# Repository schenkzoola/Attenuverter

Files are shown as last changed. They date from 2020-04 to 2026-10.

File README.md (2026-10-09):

<picture>
  <source media="(prefers-color-scheme: dark)" srcset="docs/images/logo-light.png">
  Schenktronics
</picture>

# Attenuverter

A 6HP Eurorack quad attenuverter from **Schenktronics**. Each of its four channels scales a signal by anywhere from ×1, through zero, to ×−1 (inverted), with a click at zero. Every input is normalled to +5 V, so with nothing plugged in, each channel is a manual offset from −5 V to +5 V.

Attenuverter front panel

## Features

- 6HP Eurorack, 20 mm deep. 16 mA on +12 V and 9 mA on −12 V.
- Four channels, each turning a signal down, off, or upside down
- Knobs with a printed zero mark, straight up at the top of travel
- Inputs normalled to +5 V: four manual offset voltages when nothing's plugged in
- Reverse-power protection on both rails

## Documentation

| Document | For | PDF |
|---|-----|-----|
| [User Manual](docs/manual.md) | Using the module | [PDF](docs/pdf/attenuverter-manual.pdf) |
| [Assembly Guide](docs/assembly-guide.md) | Building the kit | [PDF](docs/pdf/attenuverter-assembly-guide.pdf) |
| [Bill of Materials](docs/BOM.md) ([CSV](docs/BOM.csv)) | Parts and sourcing | |

## Repository layout

```
hardware/
  attenuverter/                Main PCB (KiCad 10)
    Attenuverter.kicad_sch       Schematic
    Attenuverter.kicad_pcb       PCB layout
    Attenuverter.step            3D model
    attenuverter BOM.xlsx        Original BOM spreadsheet
  panel/                       Faceplate (KiCad 10, made as an aluminium PCB)
    AttenuverterFaceplate.kicad_pcb  Faceplate layout
manufacturing/
  attenuverter/                Gerbers, drill and placement files for the main PCB
  panel/                       Gerbers, drill files and the panel drawing (.dxf)
docs/                         Manual, assembly guide, BOM, images
  drawings/                     Scripts that generate the drawings
  pdf/                          PDF versions and their build settings
```

## Fabrication

| Board | Size | Layers | Thickness | Notes |
|---|---|---|---|---|
| Main PCB | 30 × 100 mm | 2 | 1.6 mm | Standard green is fine |
| Faceplate | 30 × 128.5 mm | 1 | 1.6 mm | Aluminium PCB, white solder mask, black silkscreen. Only the front copper layer is used, so FR4 works too. |

Upload the matching `*Gerbers.zip` to any common PCB fab.

## License

This hardware design and its documentation are licensed under [CC BY-NC-SA 4.0](https://creativecommons.org/licenses/by-nc-sa/4.0/). See [LICENSE](LICENSE).

The Schenktronics name and logo are trademarks of Nathan Schenk and are not covered by the CC BY-NC-SA 4.0 license.

## Links

- Tindie: <https://www.tindie.com/products/schenktronics/attenuverter/>
- ModularGrid: <https://modulargrid.net/e/schenktronics-attenuverter>
- Build video: <https://www.youtube.com/watch?v=QJxtZVHBpq0>
- Website: <https://schenktronics.com>

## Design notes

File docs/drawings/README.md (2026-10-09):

# Drawings

The drawings in the docs are generated by three scripts in this repo, plus one that lives elsewhere (see "Outline drawings" below). The three here use only the Python standard library.

| Script | Makes | From |
|---|---|---|
| [`make_panel_svg.py`](make_panel_svg.py) | `panel.svg`, used in the manual, and `panel-plain.svg`, the panel without captions, used on packaging labels | The faceplate KiCad file |
| [`make_assembly_svgs.py`](make_assembly_svgs.py) | `assembly-*.svg`, used in the assembly guide | The main PCB KiCad file |
| [`make_patch_svgs.py`](make_patch_svgs.py) | `patch-*.svg`, the patch examples in the manual | The faceplate KiCad file |

## Panel drawing

The panel drawing in the [user manual](../manual.md) ([`../images/panel.svg`](../images/panel.svg)) is generated from the KiCad faceplate file, [`AttenuverterFaceplate.kicad_pcb`](../../hardware/panel/AttenuverterFaceplate.kicad_pcb).

After changing the faceplate in KiCad, run this from anywhere in the repo:

```sh
python3 docs/drawings/make_panel_svg.py
```

### What it reads

| From the KiCad file | Used for |
|---|---|
| `Edge.Cuts` lines | Panel outline |
| Mounting-hole footprints and their drill sizes | Jacks (Ø6.0), the knobs (Ø7.0) and the rack screw holes |
| `F.SilkS` lines, arcs and text | The channel outlines, the knob scales and the title |
| `F.SilkS` circles | The black rings around the outputs |
| The logo footprint's `F.SilkS` polygons | The Schenktronics logo |

The script tells holes apart by drill size, so if you change a hole size, update `JACK` and `POT` at the top of the script. The knobs are drawn by the script, and the captions ("In 1", "Knob 1" and so on) are added by the script, not read from KiCad.

## Assembly drawings

After changing the main PCB in KiCad, run:

```sh
python3 docs/drawings/make_assembly_svgs.py
```

| Drawing | How it's made |
|---|---|
| `assembly-1-smd.svg` | Back board view, drawn from the pads, back silkscreen and references in the PCB file. U1's pin 1 and the diodes' cathode pads (pad 1) are marked red. |
| `assembly-2-header.svg` | Back board view with J7's outline. The notch position is the gap in the footprint's outline, set in `fig_header()`. |
| `assembly-3-parts.svg` | Front board view, drawn from the board outline, pads and front silkscreen |
| `assembly-4-faceplate.svg` | Side diagram. The part positions along the board come from the PCB file, and the heights are approximate. |
| `assembly-5-solder.svg` | Back board view, with the pot and jack pads to solder |

The side view assumes the faceplate sits 10 mm further up than the PCB, matching the two KiCad files. If you move the parts on either board, update `OFFSET` near the top of the figures section.

## Patch examples

The patch drawings reuse the panel drawing and add module boxes and cables. Each example is a short function in the script, for example:

```python
def invert_envelope(data):
    p = Patch(data)
    p.source("In 1", "Envelope", "out")
    p.dest("Out 1", "Filter", "cutoff CV in")
    p.turn("Knob 1", -110)
    p.note("Knob 1", "Knob 1 left", "upside-down envelope")
    ...
```

Jacks and knobs are named `In 1`–`In 4`, `Out 1`–`Out 4` and `Knob 1`–`Knob 4`, from the top. Sources go on the left, destinations on the right. `turn()` sets a knob's pointer, in degrees from the center click (negative is anticlockwise). `note()` puts a caption to the left of a knob or jack. Pass `color=BLUE` to draw a second signal. To add an example, write a new function, add it to the list in `main()`, and run:

```sh
python3 docs/drawings/make_patch_svgs.py
```

## Outline drawings

`outline-front.svg`, `outline-side.svg`, one `outline-iso-{top,bottom}-{left,right}.svg` per corner, and `outline-bare-parts.svg` (the panel and bare PCB side by side, for the assembly guide's "before you start" shot) are real projections straight from [`ST-03_Attenuverter.step`](../../hardware/ST-03_Attenuverter.step) in `hardware/` — not diagrams. They replace the old product photos in the README, manual and assembly guide. All four isometric corners are generated every run so there's always a fresh set to pick a hero shot from; `outline-iso-top-left.svg` is the one currently used.

**The generator for these doesn't live in this repo.** Unlike the three scripts above, it needs no product-specific logic — point it at any product's STEP files and it works unchanged — so it's kept as one shared tool in the private `schenktronics-business` repo (`claude/skills/schenktronics-product-docs/assets/drawings/make_outline_svg.py`) rather than forked into every product. Regenerate from this repo's root:

```sh
pip install cadquery  # no FreeCAD or other CAD tooling needed
python3 ~/Products/schenktronics-business/claude/skills/schenktronics-product-docs/assets/drawings/make_outline_svg.py \
  --assembly hardware/ST-03_Attenuverter.step \
  --panel hardware/panel/AttenuverterFaceplate.step \
  --board hardware/attenuverter/Attenuverter.step \
  --out docs/images \
  --product "Attenuverter"
```

(or add a view name at the end, e.g. `... outline-front.svg`, to regenerate just that one)

**This is slow, and not predictably so — read the module docstring in that script before touching it.** Short version: a straight-on view down an axis where many cylindrical parts line up end-on (every jack here, viewed from the front — nine of them, more than either the Multiple or Levels) is a degenerate case for exact-BRep HLR. The fix that works for this — a perspective projection with its apex centered on the model, not tilting the orthographic direction — is explained in full in the script itself. That script is the one copy serving every product, so fixes and lessons belong there, not duplicated into each product repo's own docs.

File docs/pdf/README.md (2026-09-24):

# PDFs

Printable versions of the docs:

- [User Manual (PDF)](attenuverter-manual.pdf)
- [Assembly Guide (PDF)](attenuverter-assembly-guide.pdf)

These are built from [`../manual.md`](../manual.md) and [`../assembly-guide.md`](../assembly-guide.md). **Don't edit the PDFs by hand.** Edit the Markdown instead.

The build tool lives in [schenktronics-docs-tools](https://github.com/schenkzoola/schenktronics-docs-tools), so this repo only holds its settings, in [`config.json`](config.json): the product name, PCB version and which documents to build.

## Automatic builds

The [Build PDFs workflow](../../.github/workflows/pdf.yml) rebuilds the PDFs whenever the docs, their images or `config.json` change on `master`, and commits the new PDFs back. After you push a docs change, wait a minute and then `git pull` to get the rebuilt PDFs.

After an update to schenktronics-docs-tools, run the workflow by hand from the repo's **Actions** tab to rebuild with the new version.

## Previewing locally

See [Previewing locally](https://github.com/schenkzoola/schenktronics-docs-tools#previewing-locally) in the tools repo. In short:

```sh
node ~/Products/schenktronics-docs-tools/pdf/build.mjs docs/pdf/config.json
```

Don't commit the PDFs this produces. Let the workflow build the committed copies.

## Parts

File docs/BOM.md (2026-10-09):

# Bill of Materials — Attenuverter v1.0

A machine-readable copy is in [BOM.csv](BOM.csv). The original spreadsheet is [hardware/attenuverter/attenuverter BOM.xlsx](<../hardware/attenuverter/attenuverter BOM.xlsx>).

All the resistors, capacitors, diodes, fuses and chips are surface-mount parts on the back of the board. The resistors and capacitors are 0805 size. Parts marked "or equivalent" can be swapped for any part with the same value, package and pinout.

The **Easy Build Kit** includes a PCB with every surface-mount part below already soldered and tested — you only need to source the through-hole parts.

## Surface-mount parts (back of the board)

| Qty | Reference | Part | Manufacturer / Part No. | Notes |
|----:|---|---|---|---|
| 1 | U1 | Quad JFET op-amp, SOIC-14 | Texas Instruments TL074CDR (TI, Microchip or Analog Devices only) | [Datasheet](https://www.ti.com/lit/ds/symlink/tl074.pdf) |
| 1 | U2 | 5.0 V shunt voltage reference, SOT-23-3 | Texas Instruments LM4040D50IDBZR (TI, Microchip or Analog Devices only) | [Datasheet](https://www.ti.com/lit/ds/symlink/lm4040.pdf). Cathode on pin 1, anode on pin 2. Sets the +5 V that unplugged inputs receive. |
| 16 | R1, R2, R4, R5, R6, R7, R9, R10, R12, R13, R15, R16, R17, R18, R20, R21 | Resistor, 100 kΩ, 1%, 0805 | Yageo RC0805FR-07100KL, or equivalent | |
| 13 | R3, R8, R11, R14, R19, R22–R29 | Resistor, 1 kΩ, 1%, 0805 | Yageo RC0805FR-071KL, or equivalent | R3, R8, R14 and R19 are the output resistors, one per channel. R11 feeds the 5 V reference. R22–R29 are part of the input protection. |
| 4 | C1, C2, C3, C7 | Capacitor, 10 pF, 50 V, C0G/NP0, 0805 | Yageo CC0805JRNPO9BN100, or equivalent | |
| 3 | C4, C6, C9 | Capacitor, 100 nF, 25 V, X7R, 0805 | AVX 08053C104KAT2A, or equivalent | |
| 2 | C5, C8 | Capacitor, 10 µF, 25 V, X5R, 0805 | Taiyo Yuden TMK212BBJ106KG-T, or equivalent | |
| 2 | D1, D2 | Diode, 1 A, 300 V, SMA | ON Semiconductor MRA4003T3G, or equivalent | Reverse-power protection. The cathode (stripe) end matters. |
| 9 | D3–D11 | Diode, 1N4148, SOD-323, 75 V, 150 mA | Diodes Incorporated 1N4148WS-7-F, or equivalent | [Datasheet](https://datasheet.octopart.com/1N4148WS-7-F-Diodes-Inc.-datasheet-7284054.pdf). Input protection. The cathode (stripe) end matters. |
| 2 | F1, F2 | Resettable fuse (PTC), 200 mA hold, 30 V, 1206 | Bel Fuse 0ZCJ0020FF2E, or equivalent | Either way round |

## Through-hole parts

| Qty | Reference | Part | Manufacturer / Part No. | Notes |
|----:|---|---|---|---|
| 1 | J7 | Shrouded pin header, 2 × 5, 2.54 mm, vertical | On Shore Technology 302-S101, or equivalent | Eurorack power connector. Fits on the back. |
| 8 | J1–J6, J8, J9 | 3.5 mm mono switched jack, vertical PCB mount, with nut | QingPu WQP-PJ398SM or WQP518MA, or equivalent. Either one works. CUI MJ-3507 also works, with a ground wire. | [Datasheet / product page](http://www.qingpu-electronics.com/en/products/WQP-PJ398SM-362.html). The inputs use the switched contact for the +5 V normal. The footprint also takes the CUI MJ-3507 ([datasheet](https://www.cuidevices.com/product/resource/mj-3507.pdf)), which is on Mouser: its tip and switch pins go into the board, and its sleeve lug needs a short wire to the jack's square ground pad. |
| 4 | RV1–RV4 | Potentiometer, 100 kΩ linear, 9 mm, vertical PCB mount with board-lock lugs, 6 mm D shaft (20 mm long), bushingless | Bourns PTV09A-4020F-B104, or equivalent | [Datasheet (PTV09 series)](https://www.bourns.com/docs/Product-Datasheets/PTV09.pdf). The panel's printed mark shows zero. No threaded bushing or nut: the pots are held by the PCB's two mounting lugs. An equivalent must fit the 9 mm footprint (3 pins in a row, 2 mounting lugs) and have a 6 mm shaft that fits the knob. |
| 4 | — | Knob, for 6 mm shaft | Davies Molding 1221-J, or equivalent | An equivalent must fit the pot's D shaft. |
| 1 | — | Main PCB, 30 × 100 mm, 2-layer, 1.6 mm FR4 | Schenktronics | Gerbers: [AttenuverterGerbers.zip](../manufacturing/attenuverter/AttenuverterGerbers.zip) |
| 1 | — | Faceplate, 6HP (30 × 128.5 mm), 1.6 mm aluminium PCB | Schenktronics | Gerbers: [AttenuverterFaceplateGerbers.zip](../manufacturing/panel/AttenuverterFaceplateGerbers.zip). Single-sided, so it can also be made in FR4. |
| 1 | — | Eurorack power cable, 10-pin to 16-pin | | Red stripe marks −12 V. |

## Not included

| Qty | Part | Notes |
|----:|---|---|
| 4 | M3 rack screws | Supplied with most Eurorack cases. Two, in diagonally opposite corners, will hold the module. |

## Ordering the parts

There's a [Mouser project](https://www.mouser.com/ProjectManager/ProjectDetail.aspx?AccessID=490ed0ce39) with the parts for building from bare PCBs. Mouser doesn't stock QingPu jacks, so the project uses CUI MJ-3507 jacks instead. They fit the board, but each one needs a ground wire: see the note in Step 6 of the [assembly guide](assembly-guide.md#step-6--solder-the-pots-and-jacks).

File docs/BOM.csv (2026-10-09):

Qty | Reference | Description | Manufacturer | Part Number | Link
1 | U1 | Quad JFET op-amp, SOIC-14. Use TI, Microchip or Analog Devices only | Texas Instruments | TL074CDR | https://www.ti.com/lit/ds/symlink/tl074.pdf
1 | U2 | 5.0V shunt voltage reference, SOT-23-3, cathode pin 1, anode pin 2. Use TI, Microchip or Analog Devices only | Texas Instruments | LM4040D50IDBZR | https://www.ti.com/lit/ds/symlink/lm4040.pdf
16 | R1, R2, R4, R5, R6, R7, R9, R10, R12, R13, R15, R16, R17, R18, R20, R21 | Resistor, 100k, 1%, 0805 | Yageo | RC0805FR-07100KL
13 | R3, R8, R11, R14, R19, R22, R23, R24, R25, R26, R27, R28, R29 | Resistor, 1k, 1%, 0805 | Yageo | RC0805FR-071KL
4 | C1, C2, C3, C7 | Capacitor, 10pF, 50V, C0G/NP0, 0805 | Yageo | CC0805JRNPO9BN100
3 | C4, C6, C9 | Capacitor, 100nF, 25V, X7R, 0805 | AVX | 08053C104KAT2A
2 | C5, C8 | Capacitor, 10uF, 25V, X5R, 0805 | Taiyo Yuden | TMK212BBJ106KG-T
2 | D1, D2 | Diode, 1A, 300V, SMA | ON Semiconductor | MRA4003T3G
9 | D3, D4, D5, D6, D7, D8, D9, D10, D11 | Diode, 1N4148, SOD-323, 75 V, 150 mA | Diodes Incorporated, or equivalent | 1N4148WS-7-F | https://datasheet.octopart.com/1N4148WS-7-F-Diodes-Inc.-datasheet-7284054.pdf
2 | F1, F2 | Resettable fuse (PTC), 200mA hold, 30V, 1206 | Bel Fuse | 0ZCJ0020FF2E
1 | J7 | Shrouded pin header, 2x5, 2.54mm, vertical | On Shore Technology | 302-S101
8 | J1-J6, J8, J9 | 3.5mm mono switched jack, vertical, with nut (CUI MJ-3507 also works, with a ground wire from its sleeve lug to the square pad) | QingPu | WQP-PJ398SM or WQP518MA | http://www.qingpu-electronics.com/en/products/WQP-PJ398SM-362.html
4 | RV1-RV4 | Potentiometer, 100k linear, 9mm, bushingless, 6mm D shaft (20mm long) (or equivalent) | Bourns | PTV09A-4020F-B104 | https://www.bourns.com/docs/Product-Datasheets/PTV09.pdf
4 |  | Knob, fits 6mm D shaft (or equivalent) | Davies Molding | 1221-J
1 |  | Main PCB, 30x100mm, 2-layer, 1.6mm | Schenktronics | Attenuverter v1.0
1 |  | Faceplate, 6HP, 1.6mm aluminium PCB | Schenktronics | Attenuverter Faceplate
1 |  | Eurorack power cable, 10-pin to 16-pin

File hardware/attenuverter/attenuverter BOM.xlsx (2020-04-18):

Manufacturer Part Number | Manufacturer | Customer Reference | Reference Designator | Quantity | Description
CC0805JRNPO9BN100 | Yageo |  | C1, C2, C3, C7 | 4 | CAP CER 10PF 50V C0G/NPO 0805
08053C104KAT2A | AVX Corporation |  | C4, C6, C9 | 3 | CAP CER 0.1UF 25V X7R 0805
TMK212BBJ106KG-T | Taiyo Yuden |  | C5, C8 | 2 | CAP CER 10UF 25V X5R 0805
MRA4003T3G | ON Semiconductor |  | D1, D2 | 2 | DIODE GEN PURP 300V 1A SMA
0ZCJ0020FF2E | Bel Fuse Inc. |  | F1, F2 | 2 | PTC RESET FUSE 30V 200MA 1206
MJ-3507 | CUI Devices |  | J1, J2, J3, J4, J5, J6, J8, J9 | 8 | CONN AUDIO JACK 3.5MM MONO
302-S101 | On Shore Technology Inc. |  | J7 | 1 | CONN HEADER VERT 10POS 2.54MM
LM4040DYM3-5.0-TR | Microchip Technology |  | U2 | 1 | IC VREF SHUNT 1% SOT23-3
RC0805FR-07100KL | Yageo |  | R1, R2, R4, R5, R6, R7, R9, R10, R12, R13, R15, R16, R17, R18, R20, R21 | 16 | RES SMD 100K OHM 1% 1/8W 0805
RC0805FR-07100RL | Yageo |  | R3, R8, R14, R19 | 4 | RES SMD 100 OHM 1% 1/8W 0805
RC0805FR-071KL | Yageo |  | R11 | 1 | RES SMD 1K OHM 1% 1/8W 0805
TL074CDR | Texas Instruments |  | U1 | 1 | IC OPAMP JFET 4 CIRCUIT 14SOIC
PTV09A-4225F-B104 | Bourns Inc. |  | RV1, RV2, RV3, RV4 | 4 | POT 100K OHM 1/20W CARBON LINEAR
1221-J | Davies Molding, LLC | Knobs |  | 4 | KNOB SERRATED 0.236" PLASTIC

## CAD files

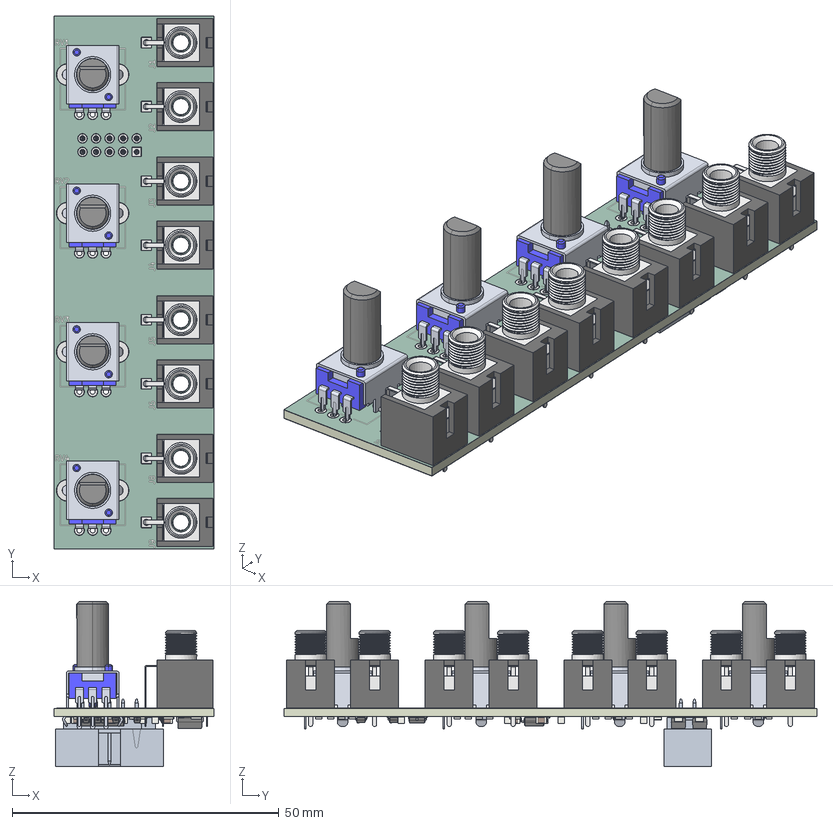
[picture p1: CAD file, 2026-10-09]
hardware/attenuverter/Attenuverter.step
30.0 x 100.0 x 31.0 mm
Thonkiconn - PJ398SM v10 x 8
PTV09A-4X20F-XXXCX_2 x 4
PTV09A-4X20F-XXXCX x 4
C_0805_2012Metric x 9
D_SMA x 2
SOT-23
R_0805_2012Metric x 29
Fuse_1206_3216Metric x 2
SOIC-14_3.9x8.7mm_P1.27mm
D_SOD-323 x 9
Attenuverter-unsaved-export-JzEjut_copper
Attenuverter-unsaved-export-JzEjut_pad
Attenuverter-unsaved-export-JzEjut_via
Attenuverter-unsaved-export-JzEjut_silkscreen x 2
Attenuverter-unsaved-export-JzEjut_soldermask x 2
Attenuverter-unsaved-export-JzEjut_PCB

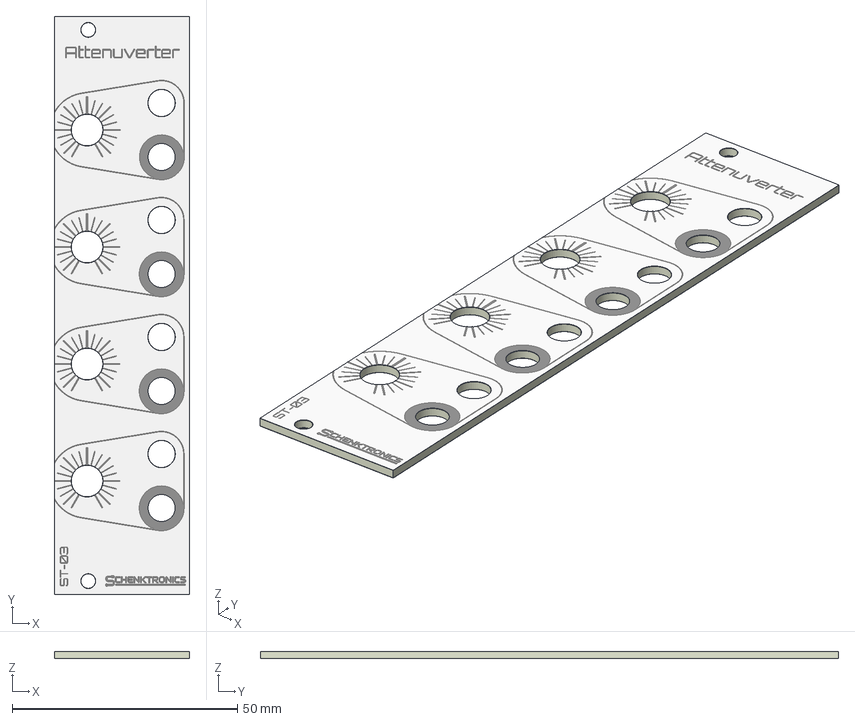
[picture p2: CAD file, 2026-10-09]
hardware/panel/AttenuverterFaceplate.step
30.0 x 128.5 x 1.64 mm
AttenuverterFaceplate-unsaved-export-2P21R3_copper
AttenuverterFaceplate-unsaved-export-2P21R3_silkscreen
AttenuverterFaceplate-unsaved-export-2P21R3_soldermask x 2
AttenuverterFaceplate-unsaved-export-2P21R3_PCB

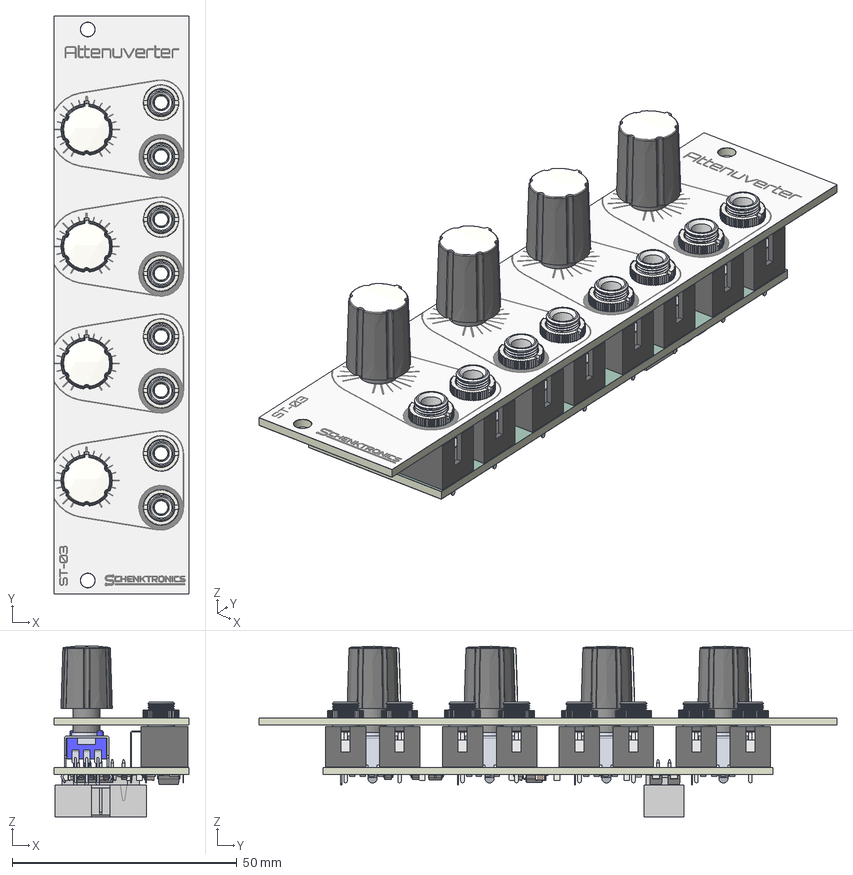
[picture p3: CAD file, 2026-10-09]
hardware/ST-03_Attenuverter.step
30.0 x 128.5 x 37.9 mm
Thonkiconn - PJ398SM v10 x 8
PTV09A-4X20F-XXXCX_2 x 4
PTV09A-4X20F-XXXCX x 4
C_0805_2012Metric_1 x 9
D_SMA_1 x 2
SOT-23_1
R_0805_2012Metric_1 x 29
Fuse_1206_3216Metric_1 x 2
SOIC-14_3.9x8.7mm_P1.27mm_1
D_SOD-323_1 x 9
Attenuverter-unsaved-export-JzEjut_copper
Attenuverter-unsaved-export-JzEjut_pad
Attenuverter-unsaved-export-JzEjut_via
Attenuverter-unsaved-export-JzEjut_silkscreen
Attenuverter-unsaved-export-JzEjut_silkscreen_1
Attenuverter-unsaved-export-JzEjut_soldermask
Attenuverter-unsaved-export-JzEjut_soldermask_1
Attenuverter-unsaved-export-JzEjut_PCB
AttenuverterFaceplate-unsaved-export-2P21R3_copper
AttenuverterFaceplate-unsaved-export-2P21R3_silkscreen
AttenuverterFaceplate-unsaved-export-2P21R3_soldermask
AttenuverterFaceplate-unsaved-export-2P21R3_soldermask_1
AttenuverterFaceplate-unsaved-export-2P21R3_PCB
Davies 1221-J x 4

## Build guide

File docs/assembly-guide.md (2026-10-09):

# Attenuverter — Assembly Guide

This kit has 139 solder joints, 85 of them on surface-mount parts: 0805 resistors and capacitors, and a SOIC-14 chip. It takes about 1½–2 hours if you're experienced with surface-mount soldering, and longer if you're not. If you haven't soldered surface-mount parts before, practice on a scrap board first, or start with a through-hole kit such as the [Passive Attenuator](https://github.com/schenkzoola/ST02-attenuator).

**Building the Easy Build Kit?** Its board arrives with every surface-mount part already soldered and tested, so skip [Step 1](#step-1--solder-the-surface-mount-parts) and start at [Step 2](#step-2--fit-the-power-header). That leaves 54 through-hole joints, about 45–60 minutes, and no surface-mount soldering at all.

**Prefer to watch?** There's a video of the whole build: [Watch me build a surface mount attenuverter!](https://www.youtube.com/watch?v=QJxtZVHBpq0)

The faceplate and the bare PCB, before assembly

## What you need

### Kit contents

Check your kit against this list before you start (full details in the [BOM](BOM.md)).

**Easy Build Kit:** your board already has these soldered on — check they're present and well soldered, don't source loose parts for them:

- [ ] 1 × TL074 quad op-amp (U1, 14 pins)
- [ ] 1 × LM4040 5 V reference (U2, 3 pins)
- [ ] 16 × 100 kΩ resistors
- [ ] 13 × 1 kΩ resistors
- [ ] 4 × 10 pF capacitors
- [ ] 3 × 100 nF capacitors
- [ ] 2 × 10 µF capacitors
- [ ] 2 × diodes (D1, D2)
- [ ] 9 × 1N4148 diodes (D3–D11)
- [ ] 2 × resettable fuses (F1, F2)

**Every kit**, loose:

- [ ] 1 × main PCB (Easy Build Kit: surface-mount parts above already soldered on)
- [ ] 1 × faceplate
- [ ] 1 × 10-pin shrouded power header
- [ ] 8 × 3.5 mm jacks with nuts
- [ ] 4 × potentiometers
- [ ] 4 × knobs
- [ ] 1 × power cable, 10-pin to 16-pin

If you're soldering the surface-mount parts yourself, the capacitors have no markings, so the three values look alike, and resistor markings vary between makers. Keep each value in its labelled strip or bag until you place it.

### Tools

- Soldering iron with a fine tip (about 330–360 °C for leaded solder)
- Thin solder, 0.5 mm or less
- Fine tweezers (Step 1 only — skip if you have the Easy Build Kit)
- Flux (a pen or syringe) and solder wick, for fixing bridges (Step 1 only — skip if you have the Easy Build Kit)
- A magnifier or loupe, to inspect the surface-mount joints
- Flush cutters
- Multimeter with continuity (beep), diode test and DC voltage modes
- Nut driver or wrench for the jack nuts (optional, but it avoids scratching the panel)

## Before you start

- The board has two sides. The **back** has the small rectangular pads for the surface-mount parts, and is printed "Attenuverter v1.0 / schenktronics.com" and "Red Stripe". The **front** has the outlines for the pots and jacks (RV1–RV4, J1–J9).
- Build in this order: surface-mount parts, then the power header, then the pots and jacks. Each stage is easier while the next one isn't in the way. (Easy Build Kit: the surface-mount stage is already done — start at the power header.)
- **Don't solder the pots or jacks until the faceplate is fitted.** The faceplate holds them in line while you solder.

## Step 1 — Solder the surface-mount parts

**Easy Build Kit: skip this step.** Your board already has these parts soldered and tested at the factory. Go to [Step 2](#step-2--fit-the-power-header).

All of these go on the back of the board. For every two-pad part, use the same method:

1. Put a little solder on one pad.
2. Hold the part with tweezers, slide it onto the pads, and reheat the tinned pad so the part settles flat.
3. Solder the other pad, then go back and touch up the first one.

Work in this order, from the most difficult part to the easiest:

1. **U1 (TL074).** Line up the dot or notch on the chip with the pin 1 pad, marked red in the drawing. Tack one corner pin, check that all 14 pins sit on their pads, then tack the opposite corner. Solder the rest. If two pins bridge, add flux and clean the bridge with wick.
2. **U2 (LM4040).** It only fits one way round: two pins on one side, one on the other.
3. **Resistors**, one value at a time:

   | Value | Where |
   |-------|-------|
   | 100 kΩ (16) | R1, R2, R4, R5, R6, R7, R9, R10, R12, R13, R15, R16, R17, R18, R20, R21 |
   | 1 kΩ (13) | R3, R8, R11, R14, R19, R22, R23, R24, R25, R26, R27, R28, R29 |

4. **Capacitors**, one value at a time. Open one strip at a time so you don't mix them up.

   | Value | Where |
   |-------|-------|
   | 10 pF (4) | C1, C2, C3, C7 |
   | 100 nF (3) | C4, C6, C9 |
   | 10 µF (2) | C5, C8 |

5. **D1 and D2.** The stripe (cathode) end goes on the red pad in the drawing: the end of the outline with the line across it. These diodes protect the module if the power cable goes in backwards, so a reversed diode shorts the power rail.
6. **D3–D11**, the nine 1N4148 input clamp diodes. The stripe end goes on the red pad, as for D1 and D2. The stripe goes on the +12 V pad for D5, D6, D8 and D10, and on the input-side pad for D4, D7, D9 and D11. A reversed clamp lets its input drift to about +11 V or −11 V, so check each one against the drawing before you solder it.
7. **F1 and F2**, the resettable fuses. They work either way round.

Back of the PCB with every surface-mount part labelled. U1's pin 1 pad and the cathode pads of D1 to D11 are red.

Check every joint with a magnifier. Each one should be a smooth fillet from the pad up the end of the part, with no bridges between U1's pins.

## Step 2 — Fit the power header

1. Push J7 into its holes from the **back**. Turn it so the notch in the shroud lines up with the gap in the printed outline. Pin 1 (the square pad) is −12 V, next to the "Red Stripe" marking.
2. Turn the board over and solder one pin on the front. Check that the header sits flat against the board; if not, reheat the pin and press it down.
3. Solder the other nine pins.

Back of the PCB with J7 outlined in red. Pin 1, the square pad, is next to the Red Stripe marking, and the shroud's notch goes at the gap in the outline.

## Step 3 — Check for shorts

Before adding the rest, check the power rails with a multimeter in diode test mode (the diode symbol). No power is needed. Probe the header pins from the front of the board. Worth doing on the Easy Build Kit too: the factory tested the surface-mount side, but you've just soldered the header yourself.

Use diode test mode, not resistance mode. Most meters test resistance at too low a voltage to turn a diode on, so a diode fitted backwards reads as an open circuit in resistance mode and looks fine. Diode test mode uses a higher voltage and shows a diode's forward voltage instead.

| Test | Expected result |
|---|---|
| Red probe on pin 9 (+12 V), black on pin 3 (ground) | OL, or a high reading. It may count up for a moment while the capacitors charge. |
| Red probe on pin 3 (ground), black on pin 1 (−12 V) | OL, or a high reading. It may count up for a moment. |
| Red probe on pin 3 (ground), black on pin 9 (+12 V) | About 0.5–0.7 V: D1 conducting. |
| Red probe on pin 1 (−12 V), black on pin 3 (ground) | About 0.5–0.7 V: D2 conducting. |
| Red probe on pin 9 (+12 V), black on pin 1 (−12 V) | OL. A reading of about 1–1.5 V means two clamp diodes on one channel are both reversed and shorting the rails. |

What a wrong reading means:

- **Near 0 V** (many meters also beep) in any test: a short. Look for a solder bridge on U1 or on the power header.
- **About 0.5–0.7 V in the first or second test:** D1 (first test) or D2 (second test) is fitted backwards. Fitted like that, it would short the rail as soon as you power on.
- **OL in the third or fourth test:** D1 or D2 is missing, fitted backwards, or not soldered.
- **About 1–1.5 V in the fifth test:** both clamp diodes of one channel are fitted backwards. That shorts the power rails through them. Check the pair in the next table.

The input clamp diodes (D3–D11) are on the back of the board, so you can test each one on its own two pads, before the pots and jacks go in. Use the same method: red probe on the plain end, black on the stripe end.

| Diode | Red probe on | Black probe on | Expected |
|---|---|---|---|
| D3 | GND pad | +5 V pad | About 0.5–0.7 V |
| D4 | −12 V pad | input-side pad | About 0.5–0.7 V |
| D5 | input-side pad | +12 V pad | About 0.5–0.7 V |
| D6 | input-side pad | +12 V pad | About 0.5–0.7 V |
| D7 | −12 V pad | input-side pad | About 0.5–0.7 V |
| D8 | input-side pad | +12 V pad | About 0.5–0.7 V |
| D9 | −12 V pad | input-side pad | About 0.5–0.7 V |
| D10 | input-side pad | +12 V pad | About 0.5–0.7 V |
| D11 | −12 V pad | input-side pad | About 0.5–0.7 V |

If a diode in this table reads OL, it's fitted backwards, missing, or not soldered.

## Step 4 — Fit the pots and jacks

1. Push the four pots into RV1–RV4 from the **front** of the PCB. Each pot fits only one way round: the three pins go in the row of three small holes and the two mounting lugs go in the large holes. The lugs clip into the board and hold the pot in place.
2. Insert the eight jacks into J1–J6, J8 and J9 from the front. Make sure each jack sits flat, with all three legs through their pads.
3. Don't solder anything yet.

Front of the PCB with the positions of RV1 to RV4 and the eight jacks highlighted

## Step 5 — Fit the faceplate

1. Remove the nuts from the jacks. The pots have no nuts.
2. Lower the faceplate over the parts. The "Attenuverter" label goes at the top, over J1 and RV1. The pot shafts go through the four larger holes.
3. Put the jack nuts back on and tighten them **finger-tight** for now.
4. Check that each pot shaft is centered in its hole, and that the PCB is parallel to the faceplate. The shafts are thinner than their holes, and nothing but the solder will hold them, so centering them now stops the knobs rubbing later. The legs have a little play in their holes, which gives you room to adjust.
5. Tighten the jack nuts snugly. Do not overtighten them, because that can crack the jack threads or mark the panel.

Exploded side view: pots and jacks on the PCB, the faceplate above them, and the jack nuts on top

## Step 6 — Solder the pots and jacks

Turn the assembly over and solder from the back of the PCB, between the surface-mount parts.

1. Tack one leg of each part: the square pad of each jack and the middle pin of each pot. Then check again that the pot shafts are still centered. If one isn't, reheat that joint and adjust.
2. Solder the remaining pins and pads.
3. Solder the eight large mounting-lug pads of the pots. They connect to ground, so they take a little longer to heat. Hold the iron on until the solder flows into the hole.
4. Trim any long leads with flush cutters.

> **Building with CUI MJ-3507 jacks** (the ones in the Mouser parts list)? Their tip and switch pins go into the board, but the sleeve is a solder lug on the jack, not a pin. Tack the tip pin instead of the square pad, then solder a short wire from each jack's sleeve lug to its square pad. Without the wire, the jack has no ground.

Back of the PCB: one pad per pot and jack to tack first is filled red, and the other pads, including the pot lugs, are outlined in red

## Step 7 — Fit the knobs

Push each knob onto its pot shaft. The flat on the shaft sets the knob's position. Turn each knob so the pointer points straight up, at the long mark on the panel. Check that each knob turns without rubbing on the panel.

## Step 8 — Test

### Without power

Repeat the Step 3 short test on the header pins. Then plug a patch cable into each jack in turn and check its sleeve against a ground pin (pins 3–8) on the header: every jack should beep.

### With power

Connect the module to your case (see [Install](#step-9--install)), with the red stripe on −12 V at both ends, and power on. If anything gets hot or smells, power off at once and check the diodes and U1.

With nothing plugged into the inputs, measure each output with the multimeter on DC volts. Plug a patch cable into the output and probe its tip and sleeve.

| Knob | Expected output |
|---|---|
| Fully clockwise | About +5 V |
| Pointer centered, at the long mark | About 0 V |
| Fully anticlockwise | About −5 V |

Then patch an LFO or other moving signal into each input in turn, and listen or watch as you turn the knob from one end to the other: the signal should shrink to nothing at the center and grow again, inverted, on the other side.

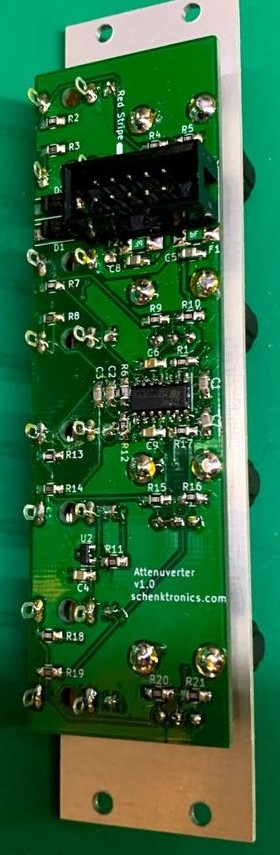
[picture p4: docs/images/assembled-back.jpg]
Back of a finished module, for comparing solder joints


## Step 9 — Install

Install the module in your case with the included power cable and four M3 rack screws (two will do). The details, and how to use the module, are in the [User Manual](manual.md#installation).

Assembled module, isometric view

## Troubleshooting

| Symptom | Likely cause |
|---|---|
| Nothing works, and the power supply struggles, a fuse trips or U1 gets hot | A short on a power rail: a solder bridge on U1, U1 fitted the wrong way round (check its pin 1), a diode fitted backwards (D1–D11), or the power cable plugged in backwards. A rail test of about 1–1.5 V points to a reversed clamp pair. |
| An unplugged input reads about +11 V, or about −11 V, instead of +5 V | One clamp diode on that input is fitted backwards. For channel 1 (RV1, jack J1) the +12 V diode is D5 and the −12 V diode is D4. For channel 2 (RV2, J3): D6 and D7. Channel 3 (RV3, J5): D8 and D9. Channel 4 (RV4, J8): D10 and D11. About +11 V means the +12 V diode is reversed, and about −11 V means the −12 V diode is. |
| No channel works, but nothing gets hot | The power header isn't soldered well. |
| Empty inputs give 0 V at every knob position | U2 or R11 isn't soldered well, or U2 is missing: the +5 V normal isn't there. |
| One channel is dead | A bad joint on that channel's jacks, pot, or its resistors and capacitor. Check the pins of U1 for that channel too. |
| An output is stuck near +10 V or −10 V | A missing or badly soldered resistor on that channel, so the op-amp has no feedback. Check the 100 kΩ resistors near it. |
| An empty input works, but a plugged-in signal doesn't come through | A bad joint on that input jack's tip leg. |
| A knob works backwards (clockwise inverts) | The pot is a different type from the one in the BOM. |
| The output isn't quite 0 V with the pointer centered | A small offset is normal. A large one means a resistor of the wrong value next to that pot: check the two 100 kΩ resistors beside it. |
| A knob rubs on the panel | The shaft isn't centered in its hole, or the knob is pushed on too far. |

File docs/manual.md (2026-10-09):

# Attenuverter — User Manual

Attenuverter front panel

## Overview

The Attenuverter is a 6HP Eurorack utility module with four identical channels. Each channel scales the signal at its input by an amount set by its knob, anywhere from full level, through zero, to full level upside down (inverted).

Each input is normalled to +5 V. With nothing plugged into an input, its output is a steady voltage from −5 V to +5 V, set by the knob. So each channel is also a manual offset or CV source.

The module is active: it needs ±12 V from your case's power supply.

## Specifications

| | |
|---|---|
| Format | Eurorack, 6HP |
| Panel | 30 × 128.5 mm |
| Depth | 20 mm |
| Power | 16 mA on +12 V, 9 mA on −12 V, no +5 V. 10-pin header. |
| Protection | Reverse-power diodes and resettable fuses on both rails, and clamp diodes on each input |
| Jacks | 8 × 3.5 mm mono (TS): 4 inputs, 4 outputs |
| Controls | 4 × knobs with a printed zero mark (100 kΩ linear potentiometers) |
| Range | ×−1 (fully anticlockwise) to 0 (center) to ×+1 (fully clockwise) |
| Unplugged inputs | +5 V, so the output is −5 V to +5 V |
| Input impedance | About 33–52 kΩ, depending on the knob (calculated) |
| Output impedance | 1 kΩ |
| Signals | Audio, CV, gates and bipolar signals. DC-coupled. |
| Output swing | About ±10 V, limited by the op-amp running on ±12 V |

Side view of the assembled module, showing the panel, PCB, jacks and pots

## Panel layout

Panel layout: four channels, each with a knob on the left, an input jack at the top right and an output jack with a black ring below it

The panel has four identical channels, numbered 1 to 4 from the top. Each channel is outlined, with its knob on the left and two jacks on the right. The top jack is the input. The jack with the **black ring** is the output.

## Using the module

### Knobs

Each knob sets how much of the input reaches the output, and which way up:

| Knob position | Output |
|---|---|
| Fully clockwise | The input, unchanged (×1) |
| Halfway between the center and fully clockwise | About a third of the input (×0.36) |
| Center | Nothing (×0) |
| Halfway between the center and fully anticlockwise | About a third of the input, inverted (×−0.36) |
| Fully anticlockwise | The input, inverted (×−1) |

"Inverted" means turned upside down: a rising envelope falls instead, and a +3 V CV becomes −3 V.

The panel prints a long mark at the top of each knob's travel, where the output is zero. Line the knob's pointer up with it to return a channel to "off".

The knobs are center-weighted. Halfway to either end gives about a third of the signal rather than half, so more of the knob's travel is spent on small amounts. That's where fine control usually matters, for example for a gentle vibrato or a small filter wobble.

### Normalled inputs: offset voltages

Each input is normalled to +5 V. When nothing is plugged into an input, the channel gets +5 V instead. The output is then a steady voltage:

- **Fully clockwise:** +5 V
- **Center:** 0 V
- **Fully anticlockwise:** −5 V

Use this as a manual CV knob for a module that has no knob of its own, to transpose a sequence, or to shift an LFO up or down through a DC mixer. Plugging a cable into the input breaks the normal.

### Using it on audio

On audio, a channel is a volume control that can also flip the phase. Mixing a signal with an inverted copy of itself cancels it out.

## Patch examples

Each drawing shows the module that sends the signal on the left and the modules that receive it on the right.

### Invert an envelope

An envelope patched into In 1, with Out 1 going to a filter's cutoff CV input and Knob 1 turned to the left

Turn Knob 1 left of center and the envelope comes out upside down: instead of opening the filter, each note closes it. Raise the filter's cutoff knob so there's somewhere for the envelope to sweep down from.

### Set the depth of an LFO

An LFO patched into In 2, with Out 2 going to a VCO's pulse width CV input and Knob 2 turned a little to the right

Many CV inputs have no level control, so a full-size LFO sweeps them from end to end. Patch the LFO through a channel and use its knob to set the depth. Just right of center gives a subtle movement; turn left of center to reverse the LFO's direction.

### Offset an LFO

An LFO through channel 3 into a DC mixer's first input, and Out 4 into the mixer's second input with In 4 empty

Channel 3 sets the LFO's depth. In 4 is empty, so Knob 4 gives a steady voltage between −5 V and +5 V. Add the two in a DC-coupled mixer and the LFO moves around a center point you choose with Knob 4.

## Good practice

- **Don't patch outputs together.** Joining an Out jack to another module's output makes the two outputs fight each other, and the result is unpredictable. The 1 kΩ output resistors help protect this module, but the other module may not be protected. Use a mixer to combine signals.
- **An empty input isn't silent.** An unplugged input carries +5 V, so its output isn't 0 V unless the knob is at the center. If a patch has an unexpected offset, check for a channel with an empty input.
- **The zero mark is close to zero, not exact.** Pots vary, so there may be a very small signal left even with the pointer lined up. If you need true silence, unplug the output.
- **Pitch CV (V/oct):** scaling a pitch CV changes the intervals, so the oscillator won't play in tune. Fully clockwise is close to ×1 but isn't calibrated for 1 V/oct. That can be a creative effect, but it's not a way to transpose. To transpose, use an empty input as an offset and add it to the pitch CV in a DC mixer.
- **Signals above about ±10 V clip.** The op-amp can't swing further than that on ±12 V. Standard Eurorack signals fit.

## Installation

1. Power off your case.
2. Connect a 10-pin to 16-pin Eurorack power cable to the header on the back of the module. The red stripe goes to **−12 V**, marked "Red Stripe" and "−12v" on the board. At the bus board end, the red stripe also goes to −12 V, usually marked on the bus.
3. Place the module in any 6HP space.
4. Secure it with four M3 rack screws, one in each corner hole. Two screws, in diagonally opposite corners, will hold it if your case is short of screws, but four look neater. Do not overtighten them.
5. Power on and check that turning a knob with an empty input moves its output between −5 V and +5 V.

The module is protected against a cable plugged in backwards, but don't rely on it. Always check the red stripe before powering on.

## Circuit

Each channel is one section of a TL074 quad op-amp (U1), wired as a differential amplifier. Each input jack goes through a 1 kΩ resistor to a node. Two clamp diodes hold that node between +12 V and −12 V, so a signal beyond about ±12 V can't reach the op-amp. From the node, the signal goes to both ends of the circuit: through a 100 kΩ resistor to the op-amp's inverting input, and to one end of the knob's potentiometer, whose other end is grounded. The pot's wiper drives the op-amp's non-inverting input. With equal 100 kΩ resistors, the output is 2 × (wiper) − (input), so it runs from −1× the input with the wiper at ground to +1× with the wiper at the input, and is zero at the center. Two 100 kΩ resistors across the two halves of each pot give the center-weighted response. A 10 pF capacitor in the feedback loop keeps the op-amp stable, and a 1 kΩ resistor protects each output.

The inputs are switched jacks. Their normalling contacts connect to a 5.0 V reference (U2, an LM4040, fed from +12 V through a 1 kΩ resistor), so each unplugged input sees +5 V.

The power input has a resettable fuse and a reverse-biased diode on each rail. If the power cable is plugged in backwards, the diodes conduct and the fuses trip, protecting the circuit. The schematic is in [hardware/attenuverter/Attenuverter.kicad_sch](../hardware/attenuverter/Attenuverter.kicad_sch).

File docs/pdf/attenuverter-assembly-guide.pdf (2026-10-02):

This kit has 139 solder joints, 85 of them on surface-mount parts: 0805 resistors and capacitors, and a SOIC-14 chip. It takes about 1½–2 hours if you're experienced with surface-mount soldering, and longer if you're not. If you haven't soldered surface-mount parts before, practice on a scrap board first, or start with a
through-hole kit such as the Passive Attenuator (https://github.com/schenkzoola/Attenuator).

Building the Easy Build Kit? Its board arrives with every surface-mount part already soldered and tested, so skip Step 1 and start at Step 2. That leaves 54 through-hole joints, about 45–60 minutes, and no surface-mount soldering at all.

Prefer to watch? There's a video of the whole build: Watch me build a surface mount attenuverter! (https://www.y

outube.com/watch?v=QJxtZVHBpq0) (https://www.youtube.com/watch?v=QJxtZVHBpq0)

## What you need

Kit contents
Check your kit against this list before you start (full details in the BOM
(https://github.com/schenkzoola/Attenuverter/blob/master/docs/BOM.md)).

Easy Build Kit: your board already has these soldered on — check they're present and well soldered, don't source loose parts for them:

1 × TL074 quad op-amp (U1, 14 pins)
1 × LM4040 5 V reference (U2, 3 pins)
16 × 100 kΩ resistors
4 × 100 Ω resistors
1 × 1 kΩ resistor
4 × 10 pF capacitors
3 × 100 nF capacitors
2 × 10 µF capacitors
2 × diodes (D1, D2)
2 × resettable fuses (F1, F2)

Every kit, loose:

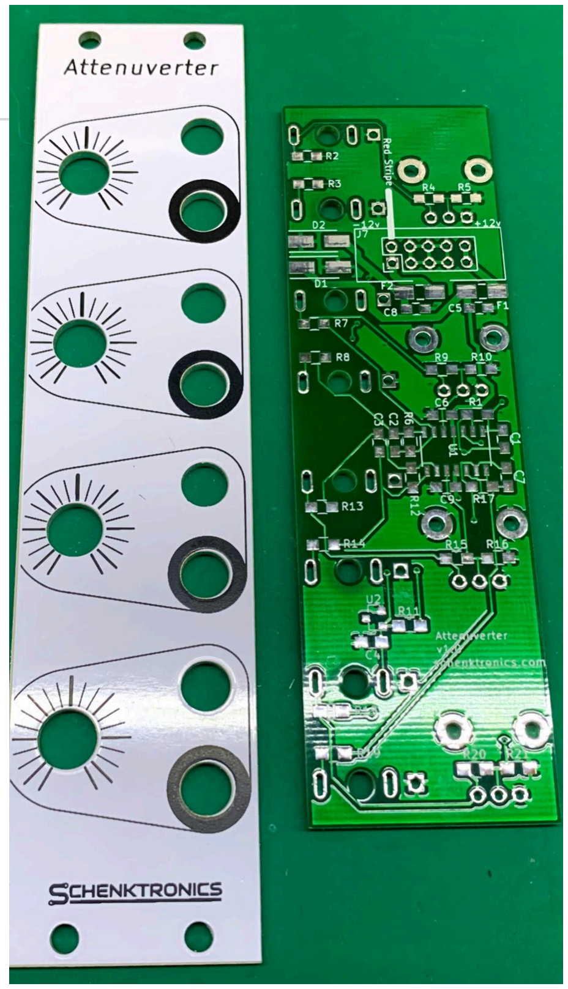
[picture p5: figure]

1 × main PCB (Easy Build Kit: surface-mount parts above already soldered on) 1 × faceplate
1 × 10-pin shrouded power header

# Attenuverter

## Assembly Guide

For PCB v1.0 · Updated 2026-10-02
Official version: github.com/schenkzoola/Attenuverter
Attenuverter · Assembly Guide · PCB v1.0 | schenktronics.com · CC BY-NC-SA 4.0 | Page 1 of 8

8 × 3.5 mm jacks with nuts
4 × potentiometers
4 × knobs
1 × power cable, 10-pin to 16-pin

If you're soldering the surface-mount parts yourself, the capacitors have no markings, so the three values look alike, and resistor markings vary between makers. Keep each value in its labelled strip or bag until you place it.

Tools
Soldering iron with a fine tip (about 330–360 °C for leaded solder)
Thin solder, 0.5 mm or less
Fine tweezers (Step 1 only — skip if you have the Easy Build Kit)
Flux (a pen or syringe) and solder wick, for fixing bridges (Step 1 only — skip if you have the Easy Build Kit) A magnifier or loupe, to inspect the surface-mount joints
Flush cutters
Multimeter with continuity (beep), diode test and DC voltage modes
Nut driver or wrench for the jack nuts (optional, but it avoids scratching the panel)

## Before you start

The board has two sides. The back has the small rectangular pads for the surface-mount parts, and is printed "Attenuverter v1.0 / schenktronics.com" and "Red Stripe". The front has the outlines for the pots and jacks (RV1–RV4, J1–J9).
Build in this order: surface-mount parts, then the power header, then the pots and jacks. Each stage is easier while the next one isn't in the way. (Easy Build Kit: the surface-mount stage is already done — start at the power header.)
Don't solder the pots or jacks until the faceplate is fitted. The faceplate holds them in line while you solder.

## Step 1 — Solder the surface-mount parts

Easy Build Kit: skip this step. Your board already has these parts soldered and tested at the factory. Go to
Step 2.

All of these go on the back of the board. For every two-pad part, use the same method:

1. Put a little solder on one pad.
2. Hold the part with tweezers, slide it onto the pads, and reheat the tinned pad so the part settles flat.
3. Solder the other pad, then go back and touch up the first one.

Work in this order, from the most difficult part to the easiest:

1. U1 (TL074). Line up the dot or notch on the chip with the pin 1 pad, marked red in the drawing. Tack one corner pin, check that all 14 pins sit on their pads, then tack the opposite corner. Solder the rest. If two pins bridge, add flux and clean the bridge with wick.
Attenuverter · Assembly Guide · PCB v1.0 | schenktronics.com · CC BY-NC-SA 4.0 | Page 2 of 8

2. U2 (LM4040). It only fits one way round: two pins on one side, one on the other.
3. Resistors, one value at a time:
Value | Where

100 kΩ (16) R1, R2, R4, R5, R6, R7, R9, R10, R12, R13, R15, R16, R17, R18, R20, R21

100 Ω (4) | R3, R8, R14, R19
1 kΩ (1) | R11
4. Capacitors, one value at a time. Open one strip at a time so you don't mix them up.
Value | Where
10 pF (4) | C1, C2, C3, C7
100 nF (3) | C4, C6, C9
10 µF (2) | C5, C8
5. D1 and D2. The stripe (cathode) end goes on the red pad in the drawing: the end of the outline with the line across it. These diodes protect the module if the power cable goes in backwards, so a reversed diode shorts the power rail.
6. F1 and F2, the resettable fuses. They work either way round.

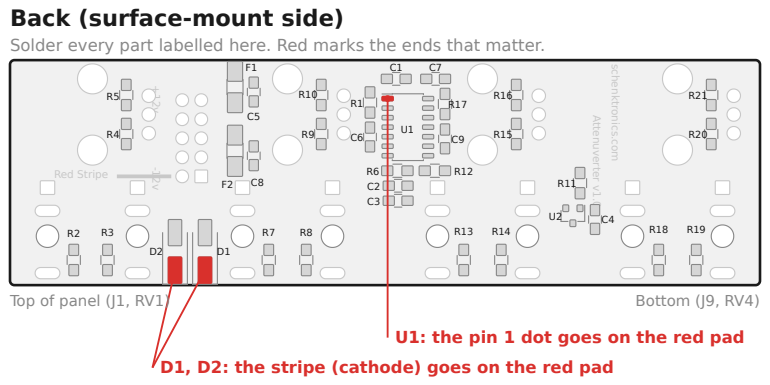
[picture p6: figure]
Back (surface-mount side); Red Stripe; schenktronics.com; Attenuverter v1.0; U1: the pin 1 dot goes on the red pad; Top of panel (J1, RV1); Bottom (J9, RV4)

Solder every part labelled here. Red marks the ends that matter.

D1, D2: the stripe (cathode) goes on the red pad

Check every joint with a magnifier. Each one should be a smooth fillet from the pad up the end of the part, with no bridges between U1's pins.

## Step 2 — Fit the power header

1. Push J7 into its holes from the back. Turn it so the notch in the shroud lines up with the gap in the printed outline. Pin 1 (the square pad) is −12 V, next to the "Red Stripe" marking.
2. Turn the board over and solder one pin on the front. Check that the header sits flat against the board; if not, reheat the pin and press it down.
3. Solder the other nine pins.
Attenuverter · Assembly Guide · PCB v1.0 | schenktronics.com · CC BY-NC-SA 4.0 | Page 3 of 8

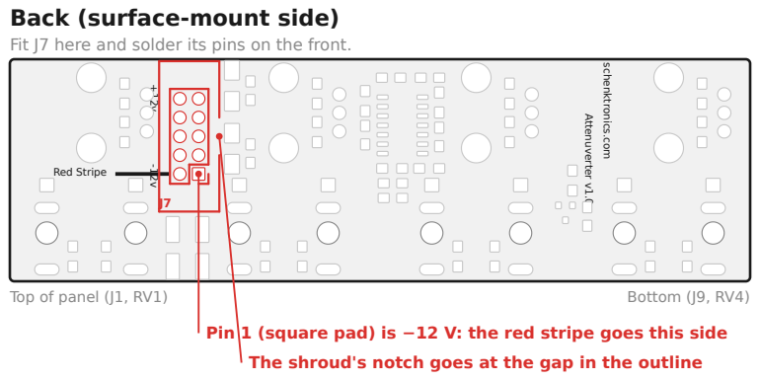
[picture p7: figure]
Back (surface-mount side); Red Stripe; schenktronics.com; Attenuverter v1.0; Top of panel (J1, RV1); Bottom (J9, RV4)

Fit J7 here and solder its pins on the front.

Pin 1 (square pad) is −12 V: the red stripe goes this side The shroud's notch goes at the gap in the outline

## Step 3 — Check for shorts

Before adding the rest, check the power rails with a multimeter in diode test mode (the diode symbol). No power is needed. Probe the header pins from the front of the board. Worth doing on the Easy Build Kit too: the factory tested the surface-mount side, but you've just soldered the header yourself.

Use diode test mode, not resistance mode. Most meters test resistance at too low a voltage to turn a diode on, so a diode fitted backwards reads as an open circuit in resistance mode and looks fine. Diode test mode uses a higher voltage and shows a diode's forward voltage instead.

Test | Expected result
Red probe on pin 9 (+12 V), black on pin 3 (ground) | OL, or a high reading. It may count up for a moment while the capacitors charge.
Red probe on pin 3 (ground), black on pin 1 (−12 V) | OL, or a high reading. It may count up for a moment.
Red probe on pin 3 (ground), black on pin 9 (+12 V) | About 0.5–0.7 V: D1 conducting.
Red probe on pin 1 (−12 V), black on pin 3 (ground) | About 0.5–0.7 V: D2 conducting.

What a wrong reading means:

Near 0 V (many meters also beep) in any test: a short. Look for a solder bridge on U1 or on the power header.
About 0.5–0.7 V in the first or second test: D1 (first test) or D2 (second test) is fitted backwards. Fitted like that, it would short the rail as soon as you power on.
OL in the third or fourth test: D1 or D2 is missing, fitted backwards, or not soldered.

## Step 4 — Fit the pots and jacks

1. Push the four pots into RV1–RV4 from the front of the PCB. Each pot fits only one way round: the three pins go in the row of three small holes and the two mounting lugs go in the large holes. The lugs clip into the board and hold the pot in place.
Attenuverter · Assembly Guide · PCB v1.0 | schenktronics.com · CC BY-NC-SA 4.0 | Page 4 of 8

2. Insert the eight jacks into J1–J6, J8 and J9 from the front. Make sure each jack sits flat, with all three legs through their pads.
3. Don't solder anything yet.

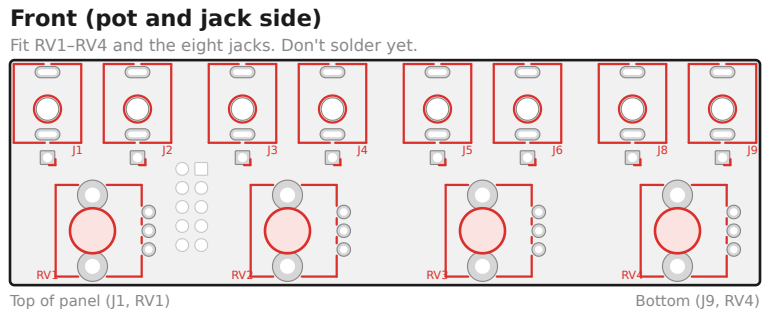
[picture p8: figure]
Front (pot and jack side); Top of panel (J1, RV1); Bottom (J9, RV4)

Fit RV1–RV4 and the eight jacks. Don't solder yet.

## Step 5 — Fit the faceplate

1. Remove the nuts from the jacks. The pots have no nuts.
2. Lower the faceplate over the parts. The "Attenuverter" label goes at the top, over J1 and RV1. The pot shafts go through the four larger holes.
3. Put the jack nuts back on and tighten them finger-tight for now.
4. Check that each pot shaft is centered in its hole, and that the PCB is parallel to the faceplate. The shafts are thinner than their holes, and nothing but the solder will hold them, so centering them now stops the knobs rubbing later. The legs have a little play in their holes, which gives you room to adjust.
5. Tighten the jack nuts snugly. Do not overtighten them, because that can crack the jack threads or mark the

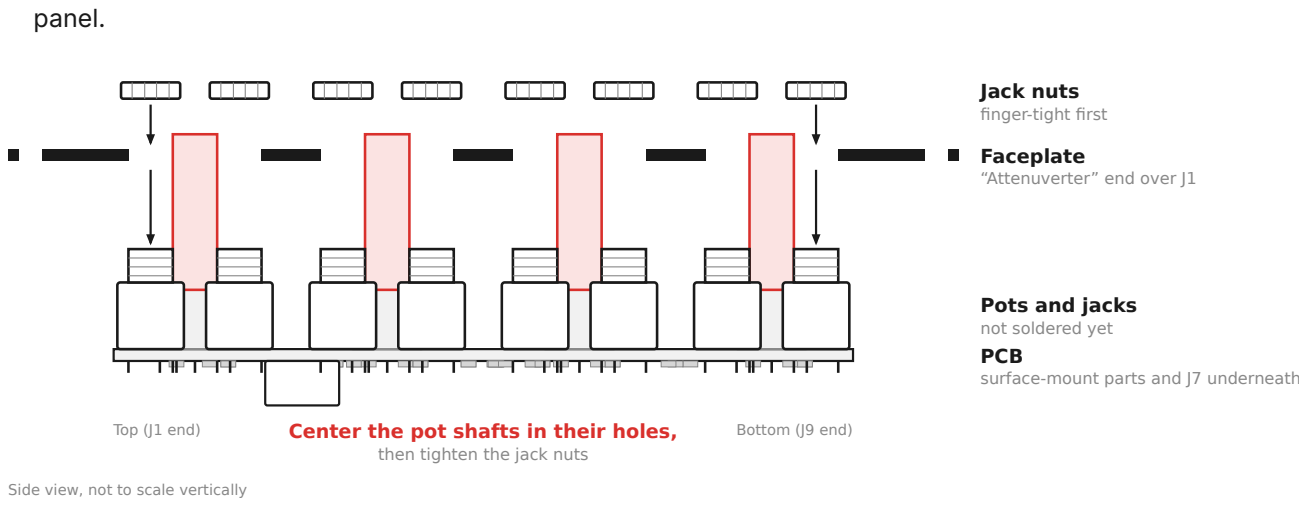
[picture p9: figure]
panel.; Jack nuts finger-tight first; Faceplate “Attenuverter” end over J1; Pots and jacks not soldered yet PCB surface-mount parts and J7 underneath; Center the pot shafts in their holes, then tighten the jack nuts; Top (J1 end); Bottom (J9 end); Side view, not to scale vertically

## Step 6 — Solder the pots and jacks

Turn the assembly over and solder from the back of the PCB, between the surface-mount parts.

1. Tack one leg of each part: the square pad of each jack and the middle pin of each pot. Then check again that the pot shafts are still centered. If one isn't, reheat that joint and adjust.
2. Solder the remaining pins and pads.
Attenuverter · Assembly Guide · PCB v1.0 | schenktronics.com · CC BY-NC-SA 4.0 | Page 5 of 8

3. Solder the eight large mounting-lug pads of the pots. They connect to ground, so they take a little longer to heat. Hold the iron on until the solder flows into the hole.
4. Trim any long leads with flush cutters.

Building with CUI MJ-3507 jacks (the ones in the Mouser parts list)? Their tip and switch pins go into the board, but the sleeve is a solder lug on the jack, not a pin. Tack the tip pin instead of the square pad, then solder a short wire from each jack's sleeve lug to its square pad. Without the wire, the jack has no ground.

Back (surface-mount side)

-12v +12v

Red Stripe

schenktronics.com

Attenuverter v1.0

Top of panel (J1, RV1) | Bottom (J9, RV4)
1. Tack these first: one leg per pot and jack (12 joints)
2. Then the rest, including the 8 large pot lugs (32 joints)

## Step 7 — Fit the knobs

Push each knob onto its pot shaft. The flat on the shaft sets the knob's position. Turn each knob to its center click and check that the pointer points straight up, at the long mark on the panel. Check that each knob turns without rubbing on the panel.

## Step 8 — Test

Without power
Repeat the Step 3 short test on the header pins. Then plug a patch cable into each jack in turn and check its sleeve against a ground pin (pins 3–8) on the header: every jack should beep.

With power
Connect the module to your case (see Install), with the red stripe on −12 V at both ends, and power on. If anything gets hot or smells, power off at once and check the diodes and U1.

With nothing plugged into the inputs, measure each output with the multimeter on DC volts. Plug a patch cable into the output and probe its tip and sleeve.

Knob | Expected output
Fully clockwise | About +5 V
Center click | About 0 V
Fully anticlockwise | About −5 V
Attenuverter · Assembly Guide · PCB v1.0 | schenktronics.com · CC BY-NC-SA 4.0 | Page 6 of 8

Then patch an LFO or other moving signal into each input in turn, and listen or watch as you turn the knob from one end to the other: the signal should shrink to nothing at the center and grow again, inverted, on the other side.

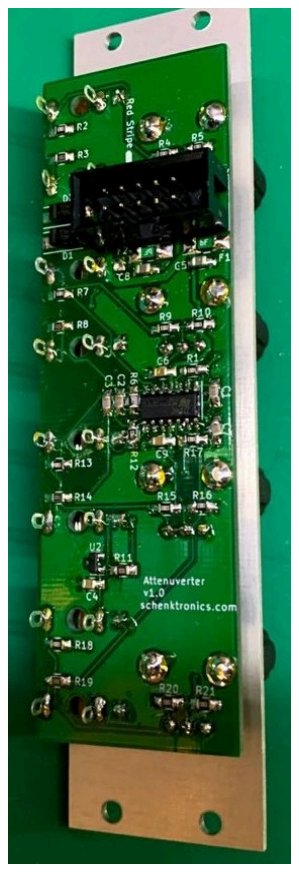
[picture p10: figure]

## Step 9 — Install

Install the module in your case with the included power cable and four M3 rack screws (two will do). The
details, and how to use the module, are in the User Manual (https://github.com/schenkzoola/Attenuverter/blob/master/docs/ma nual.md#installation). (https://github.com/schenkzoola/Attenuverter/blob/master/docs/manual.md#installation)
Attenuverter · Assembly Guide · PCB v1.0 | schenktronics.com · CC BY-NC-SA 4.0 | Page 7 of 8

## Troubleshooting

Symptom | Likely cause
Nothing works, and the power supply struggles, a fuse trips or U1 gets hot | A short on a power rail: a solder bridge on U1, U1 fitted the wrong way round (check its pin 1), a diode fitted backwards, or the power cable plugged in backwards.
No channel works, but nothing gets hot | The power header isn't soldered well.
Empty inputs give 0 V at every knob position | U2 or R11 isn't soldered well, or U2 is missing: the +5 V normal isn't there.
One channel is dead | A bad joint on that channel's jacks, pot, or its resistors and capacitor. Check the pins of U1 for that channel too.
An output is stuck near +10 V or −10 V | A missing or badly soldered resistor on that channel, so the op-amp has no feedback. Check the 100 kΩ resistors near it.
An empty input works, but a plugged- in signal doesn't come through | A bad joint on that input jack's tip leg.
A knob works backwards (clockwise inverts) | The pot is a different type from the one in the BOM.
The center click isn't at 0 V | A small offset is normal. A large one means a resistor of the wrong value next to that pot: check the two 100 kΩ resistors beside it.
A knob rubs on the panel | The shaft isn't centered in its hole, or the knob is pushed on too far.
Attenuverter · Assembly Guide · PCB v1.0 | schenktronics.com · CC BY-NC-SA 4.0 | Page 8 of 8

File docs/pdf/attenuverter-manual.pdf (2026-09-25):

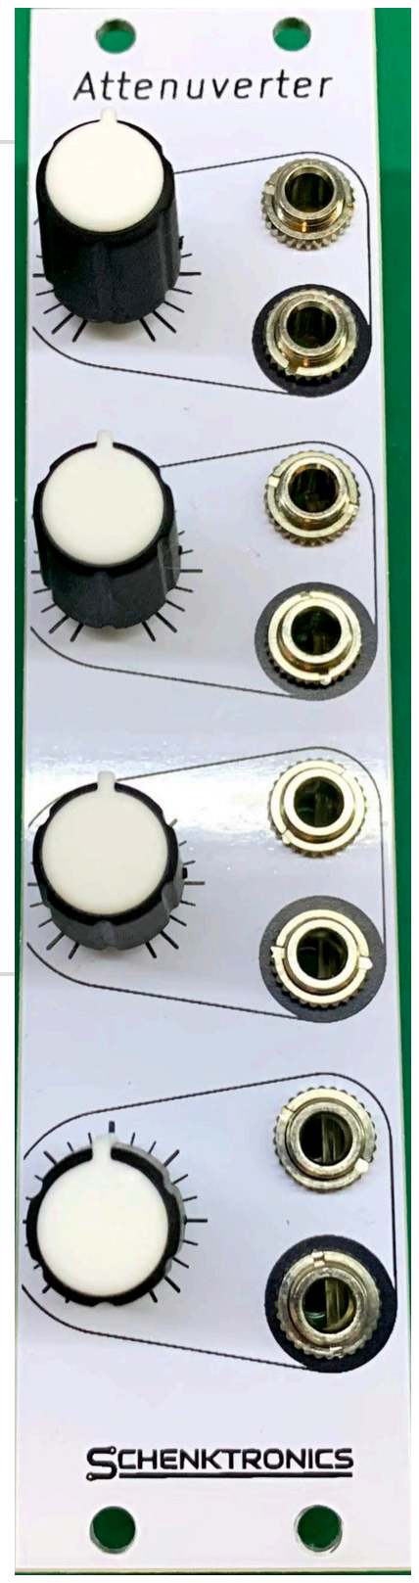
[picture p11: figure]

## Overview

The Attenuverter is a 6HP Eurorack utility module with four identical channels. Each channel scales the signal at its input by an amount set by its knob, anywhere from full level, through zero, to full level upside down (inverted).

Each input is normalled to +5 V. With nothing plugged into an input, its output is a steady voltage from −5 V to +5 V, set by the knob. So each channel is also a manual offset or CV source.

The module is active: it needs ±12 V from your case's power supply.

## Specifications

Format | Eurorack, 6HP
Panel | 30 × 128.5 mm
Depth | 20 mm
Power | 16 mA on +12 V, 9 mA on −12 V, no +5 V. 10-pin header.
Protection | Reverse-power diodes and resettable fuses on both rails
Jacks | 8 × 3.5 mm mono (TS): 4 inputs, 4 outputs
Controls | 4 × knobs with a center detent (100 kΩ linear potentiometers)
Range | ×−1 (fully anticlockwise) to 0 (center) to ×+1 (fully clockwise)
Unplugged inputs | +5 V, so the output is −5 V to +5 V
Input impedance | About 33–52 kΩ, depending on the knob (calculated)

Output impedance 100 Ω

Signals | Audio, CV, gates and bipolar signals. DC-coupled.
Output swing | About ±10 V, limited by the op-amp running on ±12 V

# Attenuverter

## User Manual

For PCB v1.0 · Updated 2026-09-24
Official version: github.com/schenkzoola/Attenuverter
Attenuverter · User Manual · PCB v1.0 | schenktronics.com · CC BY-NC-SA 4.0 | Page 1 of 5

## Panel layout

Attenuverter
In 1
input. Unplugged: +5 V
Knob 1
right ×1 · top 0 · left ×−1
Out 1
black ring = output

Channel 2
same as channel 1

Channel 3
same as channel 1

Channel 4
same as channel 1

The panel has four identical channels, numbered 1 to 4 from the top. Each channel is outlined, with its knob on the left and two jacks on the right. The top jack is the input. The jack with the black ring is the output.

## Using the module

Knobs
Each knob sets how much of the input reaches the output, and which way up:
Knob position | Output
Fully clockwise | The input, unchanged (×1)
Halfway between the center and fully clockwise | About a third of the input (×0.36)
Center (the click) | Nothing (×0)

Halfway between the center and fully anticlockwise About a third of the input, inverted (×−0.36)

Fully anticlockwise | The input, inverted (×−1)

"Inverted" means turned upside down: a rising envelope falls instead, and a +3 V CV becomes −3 V.

The knob has a click (detent) at the center, where the output is zero. It's easy to find by feel, so it's quick to return a channel to "off".

The knobs are center-weighted. Halfway to either end gives about a third of the signal rather than half, so more of the knob's travel is spent on small amounts. That's where fine control usually matters, for example for a gentle vibrato or a small filter wobble.

Attenuverter · User Manual · PCB v1.0 | schenktronics.com · CC BY-NC-SA 4.0 | Page 2 of 5

Normalled inputs: offset voltages
Each input is normalled to +5 V. When nothing is plugged into an input, the channel gets +5 V instead. The output is then a steady voltage:

Fully clockwise: +5 V
Center: 0 V
Fully anticlockwise: −5 V

Use this as a manual CV knob for a module that has no knob of its own, to transpose a sequence, or to shift an LFO up or down through a DC mixer. Plugging a cable into the input breaks the normal.

Using it on audio
On audio, a channel is a volume control that can also flip the phase. Mixing a signal with an inverted copy of itself cancels it out.

## Patch examples

Each drawing shows the module that sends the signal on the left and the modules that receive it on the right.

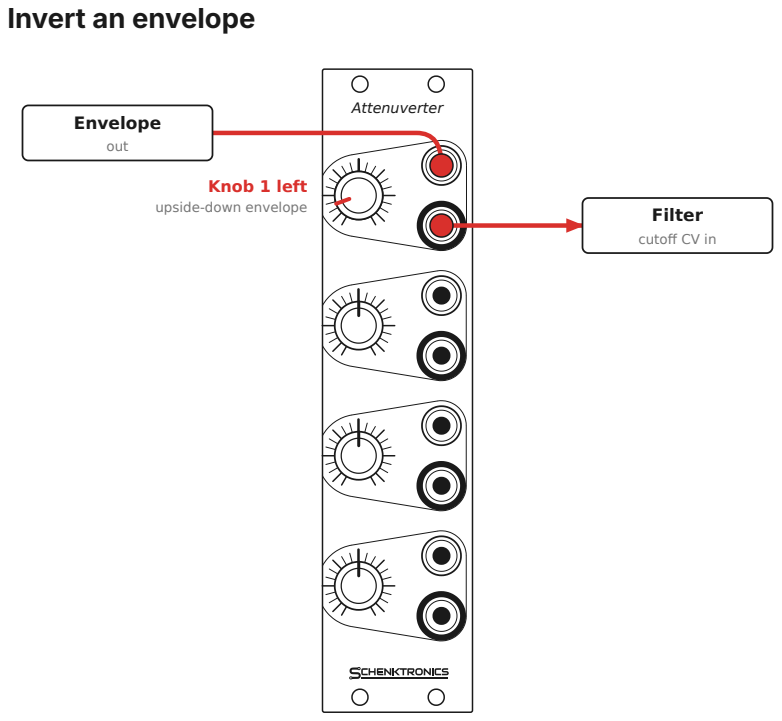
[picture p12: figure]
Invert an envelope; Attenuverter; Envelope; out; Filter; cutoff CV in; Knob 1 left upside-down envelope

Turn Knob 1 left of center and the envelope comes out upside down: instead of opening the filter, each note closes it. Raise the filter's cutoff knob so there's somewhere for the envelope to sweep down from.

Attenuverter · User Manual · PCB v1.0 | schenktronics.com · CC BY-NC-SA 4.0 | Page 3 of 5

Set the depth of an LFO

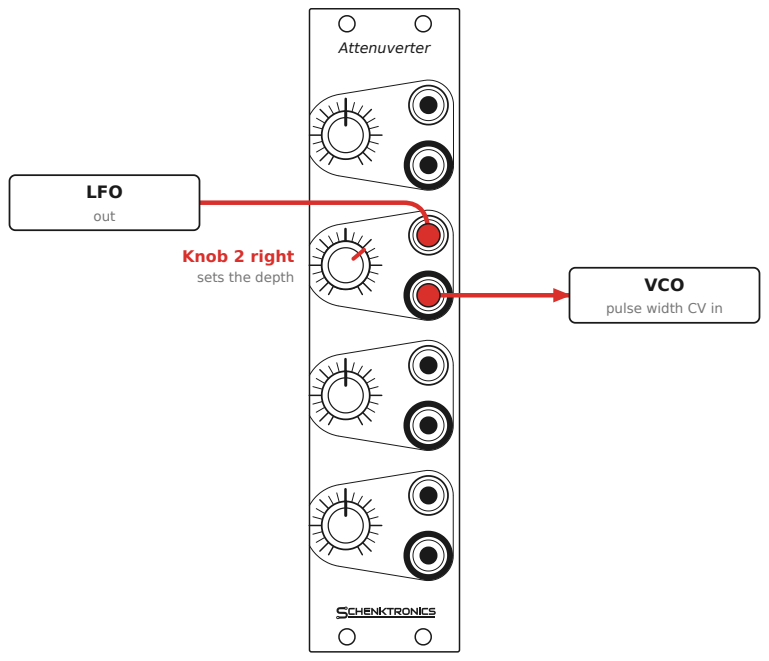
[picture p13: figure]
Attenuverter; LFO; out; VCO; pulse width CV in; Knob 2 right sets the depth

Many CV inputs have no level control, so a full-size LFO sweeps them from end to end. Patch the LFO through a channel and use its knob to set the depth. Just right of center gives a subtle movement; turn left of center to

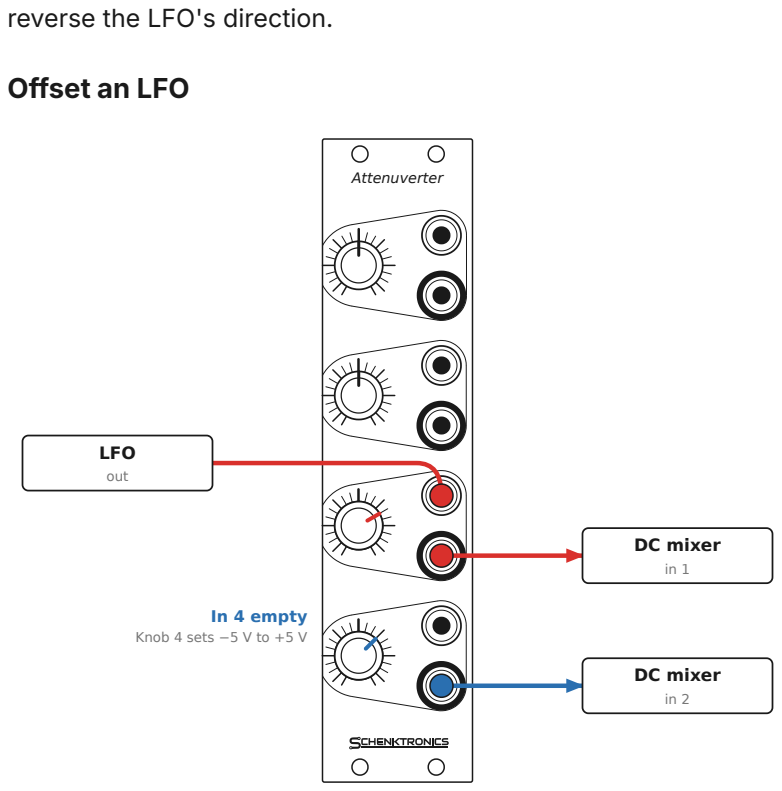
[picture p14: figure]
reverse the LFO's direction.; Offset an LFO; Attenuverter; LFO; out; DC mixer; In 4 empty Knob 4 sets −5 V to +5 V

Channel 3 sets the LFO's depth. In 4 is empty, so Knob 4 gives a steady voltage between −5 V and +5 V. Add the two in a DC-coupled mixer and the LFO moves around a center point you choose with Knob 4.

Attenuverter · User Manual · PCB v1.0 | schenktronics.com · CC BY-NC-SA 4.0 | Page 4 of 5

## Good practice

Don't patch outputs together. Joining an Out jack to another module's output makes the two outputs fight each other, and the result is unpredictable. The 100 Ω output resistors help protect this module, but the other module may not be protected. Use a mixer to combine signals.
An empty input isn't silent. An unplugged input carries +5 V, so its output isn't 0 V unless the knob is at the center. If a patch has an unexpected offset, check for a channel with an empty input.
The center click is close to zero, not exact. Pots vary, so there may be a very small signal left at the detent. If you need true silence, unplug the output.
Pitch CV (V/oct): scaling a pitch CV changes the intervals, so the oscillator won't play in tune. Fully clockwise is close to ×1 but isn't calibrated for 1 V/oct. That can be a creative effect, but it's not a way to transpose. To transpose, use an empty input as an offset and add it to the pitch CV in a DC mixer. Signals above about ±10 V clip. The op-amp can't swing further than that on ±12 V. Standard Eurorack signals fit.

## Installation

1. Power off your case.
2. Connect a 10-pin to 16-pin Eurorack power cable to the header on the back of the module. The red stripe goes to −12 V, marked "Red Stripe" and "−12v" on the board. At the bus board end, the red stripe also goes to −12 V, usually marked on the bus.
3. Place the module in any 6HP space.
4. Secure it with four M3 rack screws, one in each corner hole. Two screws, in diagonally opposite corners, will hold it if your case is short of screws, but four look neater. Do not overtighten them.
5. Power on and check that turning a knob with an empty input moves its output between −5 V and +5 V.

The module is protected against a cable plugged in backwards, but don't rely on it. Always check the red stripe before powering on.

## Circuit

Each channel is one section of a TL074 quad op-amp (U1), wired as a differential amplifier. The input goes to both ends of the circuit: through a 100 kΩ resistor to the op-amp's inverting input, and to one end of the knob's potentiometer, whose other end is grounded. The pot's wiper drives the op-amp's non-inverting input. With equal 100 kΩ resistors, the output is 2 × (wiper) − (input), so it runs from −1× the input with the wiper at ground to +1× with the wiper at the input, and is zero at the center. Two 100 kΩ resistors across the two halves of each pot give the center-weighted response. A 10 pF capacitor in the feedback loop keeps the op-amp stable, and a 100 Ω resistor protects each output.

The inputs are switched jacks. Their normalling contacts connect to a 5.0 V reference (U2, an LM4040, fed from +12 V through a 1 kΩ resistor), so each unplugged input sees +5 V.

The power input has a resettable fuse and a reverse-biased diode on each rail. If the power cable is plugged in backwards, the diodes conduct and the fuses trip, protecting the circuit. The schematic is in
Attenuverter/Attenuverter.sch (https://github.com/schenkzoola/Attenuverter/blob/master/Attenuverter/Attenuverter.sch) (KiCad 5).
Attenuverter · User Manual · PCB v1.0 | schenktronics.com · CC BY-NC-SA 4.0 | Page 5 of 5

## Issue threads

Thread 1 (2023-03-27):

pots flipped?

KeLaiFu, 2023-03-27:
Thanks for sharing this module, I am looking to use this in a project where I need an attenuverted voltage source and this looks ideal.

However, I opened the layout up in kicad and changed the footprints of the pots and jacks to ones I usually use and I noticed that when I changed the pot footprint, the wiring of them flipped. Does this mean their functionality is also flipped in the original design?

Excuse my noob questions, I am still learning as I go here...

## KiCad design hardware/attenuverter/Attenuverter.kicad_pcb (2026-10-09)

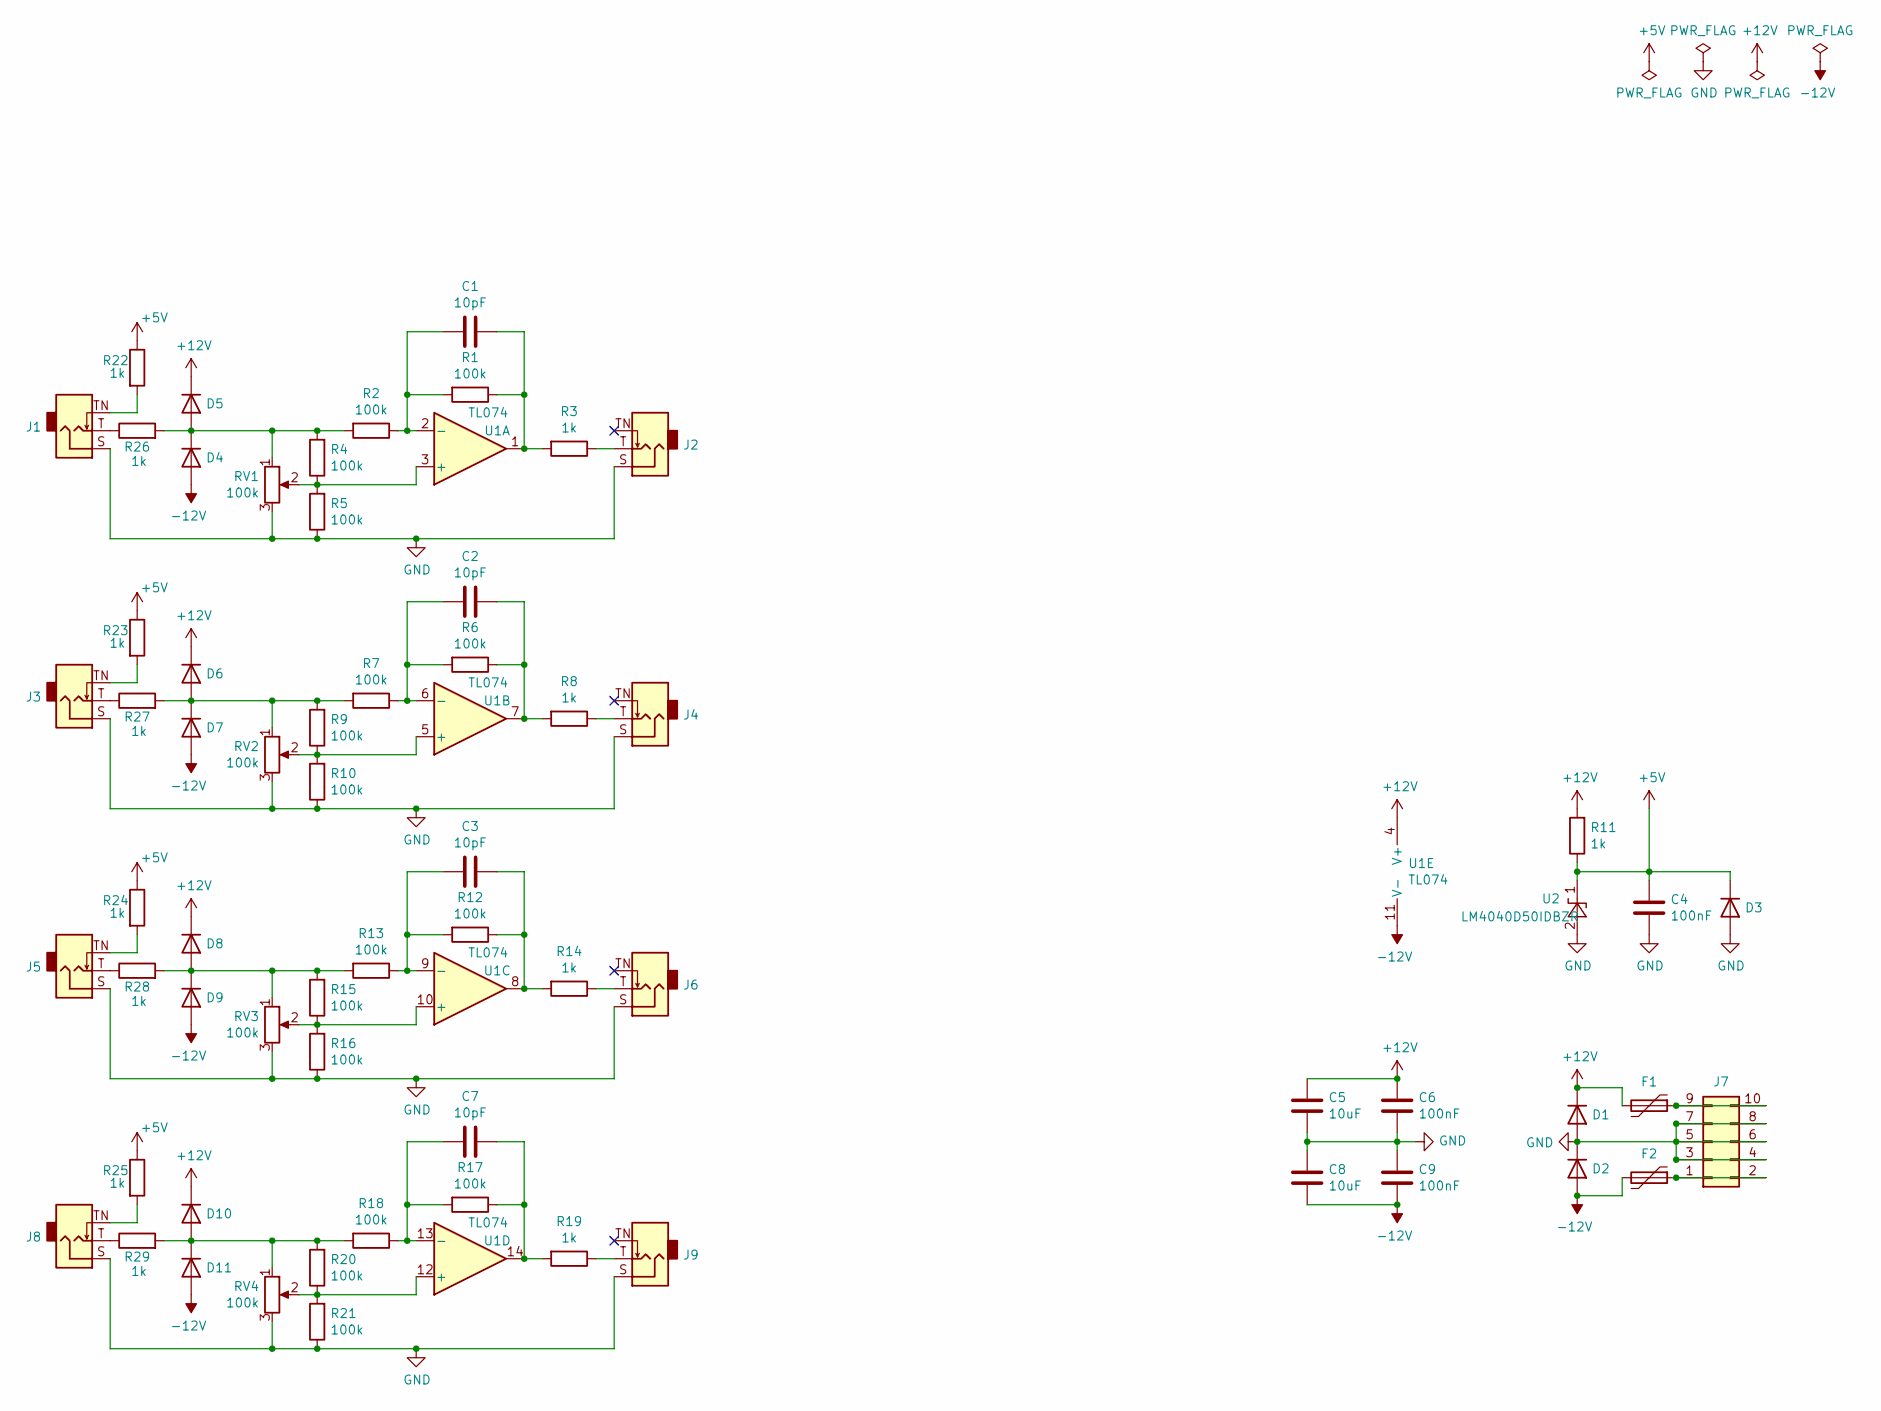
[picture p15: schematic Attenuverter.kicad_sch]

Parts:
C1, C2, C3, C7: 10pF; C_0805_2012Metric
C4, C6, C9: 100nF; C_0805_2012Metric
C5, C8: 10uF; C_0805_2012Metric
D1, D2: D; D_SMA
D3, D4, D5, D6, D7, D8, D9, D10, D11: 1N4148WS-7-F; D_SOD-323
F1, F2: Polyfuse; Fuse_1206_3216Metric
J1, J2, J3, J4, J5, J6, J8, J9: AudioJack2_SwitchT; Jack_3.5mm_QingPu_WQP-PJ398SM_Vertical_CenterHole_OvalPads
J7: Conn_02x05_Odd_Even; PinHeader_2x05_P2.54mm_Vertical_Shrouded
R1, R2, R4, R5, R6, R7, R9, R10, R12, R13, R15, R16, R17, R18, R20, R21: 100k; R_0805_2012Metric
R3, R8, R11, R14, R19, R22, R23, R24, R25, R26, R27, R28, R29: 1k; R_0805_2012Metric
RV1, RV2, RV3, RV4: 100k; Potentiometer_Alps_RK09L_Plated_Mount_Holes
U1: TL074; SOIC-14_3.9x8.7mm_P1.27mm
U2: LM4040D50IDBZR; SOT-23

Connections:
+5V: C4.1, D3.1 (K), R11.1, R22.1, R23.1, R24.1, R25.1, U2.1 (K)
+12V: C5.1, C6.1, D1.1 (K), D5.1 (K), D6.1 (K), D8.1 (K), D10.1 (K), F1.2, R11.2, U1.4 (V+)
-12V: C8.2, C9.2, D2.2 (A), D4.2 (A), D7.2 (A), D9.2 (A), D11.2 (A), F2.2, U1.11 (V-)
GND: C4.2, C5.2, C6.2, C8.1, C9.1, D1.2 (A), D2.1 (K), D3.2 (A), J1.S, J2.S, J3.S, J4.S, J5.S, J6.S, J7.3, J7.4, J7.5, J7.6, J7.7, J7.8, J8.S, J9.S, R5.1, R10.1, R16.1, R21.1, RV1.3, RV2.3, RV3.3, RV4.3, U2.2 (A)
unnamed: C1.1, R1.1, R3.2, U1.1
unnamed: C2.1, R6.1, R8.2, U1.7
unnamed: C3.1, R12.1, R14.2, U1.8
unnamed: C7.1, R17.1, R19.2, U1.14
unnamed: D4.1 (K), D5.2 (A), R2.2, R4.2, R26.2, RV1.1
unnamed: D6.2 (A), D7.1 (K), R7.2, R9.2, R27.2, RV2.1
unnamed: D8.2 (A), D9.1 (K), R13.2, R15.2, R28.2, RV3.1
unnamed: D10.2 (A), D11.1 (K), R18.2, R20.2, R29.2, RV4.1
unnamed: J1.T, R26.1
unnamed: J1.TN, R22.2
unnamed: J2.T, R3.1
unnamed: J3.T, R27.1
unnamed: J3.TN, R23.2
unnamed: J4.T, R8.1
unnamed: J5.T, R28.1
unnamed: J5.TN, R24.2
unnamed: J6.T, R14.1
unnamed: F2.1, J7.1, J7.2
unnamed: F1.1, J7.9, J7.10
unnamed: J8.T, R29.1
unnamed: J8.TN, R25.2
unnamed: J9.T, R19.1
unnamed: R4.1, R5.2, RV1.2, U1.3 (+)
unnamed: C1.2, R1.2, R2.1, U1.2 (-)
unnamed: R9.1, R10.2, RV2.2, U1.5 (+)
unnamed: C2.2, R6.2, R7.1, U1.6 (-)
unnamed: R15.1, R16.2, RV3.2, U1.10 (+)
unnamed: C3.2, R12.2, R13.1, U1.9 (-)
unnamed: R20.1, R21.2, RV4.2, U1.12 (+)
unnamed: C7.2, R17.2, R18.1, U1.13 (-)

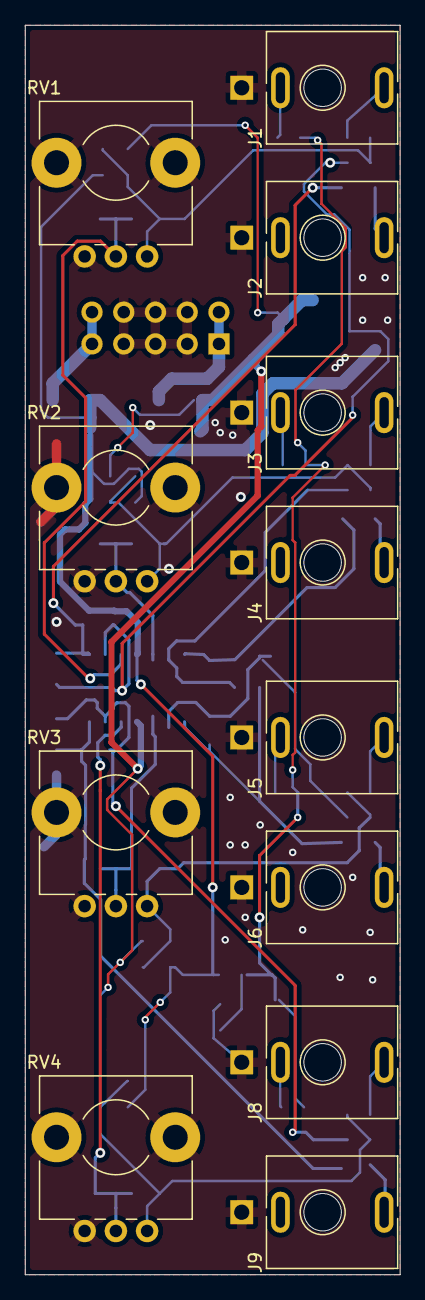
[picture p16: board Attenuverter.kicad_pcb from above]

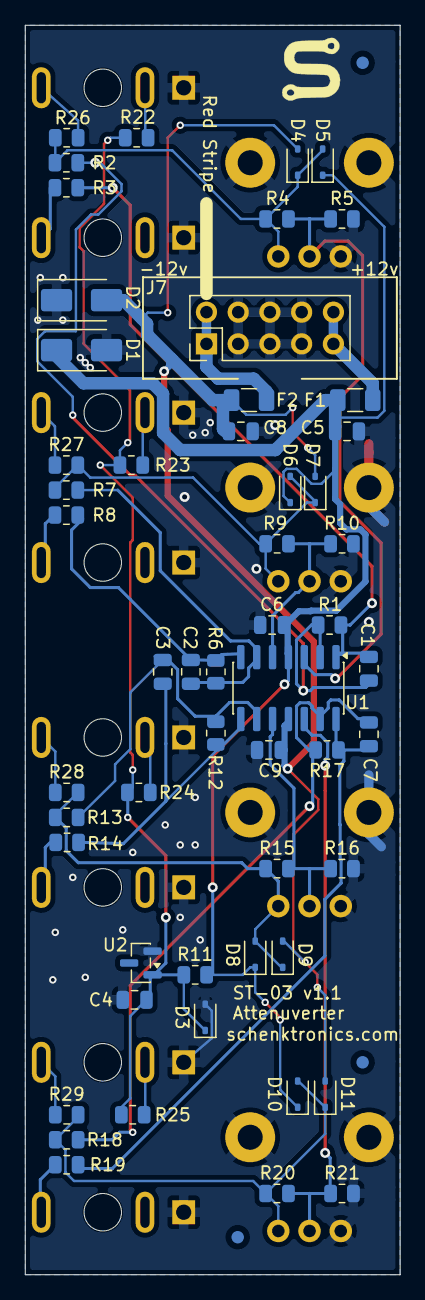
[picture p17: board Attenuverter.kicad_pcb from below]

Board: 2 copper layers, 30.0 x 100.0 mm, 69 parts (57 on the bottom side), 34 nets.

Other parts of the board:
FID1, FID2, FID3: Fiducial_1mm_Mask2mm

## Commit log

2019-11-25 Initial Commit
    Need to assign footprints and create PCB
    [Attenuverter.kicad_pcb, Attenuverter.sch]
2019-11-26 Assign footprints
    Layout Components
    Layout Board
    Add Gnd Pours
    [Attenuverter.kicad_pcb, Attenuverter.sch]
2019-11-26 Finish routing
    [Attenuverter.kicad_pcb, Attenuverter.sch]
2019-11-26 Generate gerbers and step
    [Attenuverter-B_Cu.gbr, Attenuverter-B_Mask.gbr, Attenuverter-B_Paste.gbr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]
2019-11-28 Swap inverting and non inverting inputs. Generate gerbers
    [Attenuverter-B_Cu.gbr, Attenuverter-B_Mask.gbr, Attenuverter-B_Paste.gbr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]
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2020-04-18 Add attenuverter BOM
    Remove -bak files
    [attenuverter BOM.xlsx]
2026-09-24 Add docs, drawings, BOM and PDF build for the Attenuverter
    Brings the Attenuverter repo up to the same standard as the Passive
    Multiple and Passive Attenuator: a buyer-facing README, a user manual
    with patch examples, an SMD assembly guide with tests, and a BOM that
    matches the footprints (QingPu jacks, with the CUI MJ-3507 as a
    wired alternative).
    The drawings are generated from the KiCad files by the scripts in
    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
    [BOM.csv]
2026-09-25 Use four rack screws and diode test mode in the docs
    The faceplate has four M3 holes, so the manual, assembly guide and BOM
    now say four screws, with two in opposite corners as a fallback.
    Step 3's short check now uses diode test mode. Most meters test
    resistance at too low a voltage to turn a diode on, so a backwards
    D1 or D2 read as open in resistance mode and passed. Added
    reversed-probe checks that confirm each diode is fitted correctly.
2026-10-02 Document the Easy Build Kit in the assembly guide and BOM
    Adds a skip-ahead path for the SMD-pre-populated variant: an intro
    callout, a kit-contents checklist split by what's pre-installed, and
    notes on Step 1 and Step 3 so one guide serves both the full kit and
    the Easy Build Kit.
2026-10-03 Add input protection and migrate to KiCad 10
    - Add input protection to the schematic and route it on the PCB
    - Move the project to KiCad 10 format (Attenuverter.kicad_sch/.kicad_pcb)
    - Nudge R6, R13, R14, and D11 (sub-mm) for alignment and even spacing
    [Attenuverter.kicad_pcb, Attenuverter.kicad_sch]
2026-10-03 Document input clamp diodes and 1 kΩ outputs
    - Add D3–D11 (1N4148WS-7-F) to the BOM and the assembly guide
    - Clamp each input to ±12 V through the new diodes; note the 1 kΩ input and output resistors
    - Replace the 100 Ω output resistors with 1 kΩ (R3, R8, R14, R19) and update the BOM
    - Add rail and per-diode diode test steps and troubleshooting for reversed clamps
    - Regenerate the step 1 drawing with cathode pads for D1–D11, and move the drawing
    script to a stdlib S-expression parser for KiCad 10 boards
    [BOM.csv]
2026-10-03 PCB: align jacks to faceplate, nudge reference designators, add logo
    - Move J1–J6, J8, J9 0.32 mm in X so the jack centers match the faceplate holes
    (faceplate centered on the board outline)
    - Align reference designators to their neighbours (under 1 mm moves)
    - Add the Schenktronics logo to the board
    - Reroute the traces around the moved jacks
    [Attenuverter.kicad_pcb]
2026-10-03 Switch U1 to TL074, regenerate gerbers, and source U1/U2 from TI
    - Change U1 from TL084 to TL074 in the schematic and PCB (same pinout)
    - Source U1 (TL074CDR) and U2 (LM4040DBZ-5) from TI only, per the critical-IC rule
    - Regenerate gerbers and drill files from the current board
    [Attenuverter-B_Cu.gbr, Attenuverter-B_Paste.gbr, Attenuverter-B_SilkS.gbr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]
2026-10-03 Add SMD pick-and-place file for PCBWay
    - 53 bottom-side SMD parts, positions in the same frame as the gerbers
    - Rotations normalised to 0–359°; through-hole and mechanical parts excluded
    [Attenuverter-CPL-SMD.csv]
2026-10-03 Add bottom-side fiducials and regenerate gerbers
    - Add three 1 mm fiducials (2 mm mask opening) on the bottom side, clear of the jacks
    - Move the logo off the fiducial area
    - Regenerate gerbers, drill files and the zip, including the SMD pick-and-place file
    [Attenuverter-B_Cu.gbr, Attenuverter-B_Mask.gbr, Attenuverter-B_Paste.gbr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]
2026-10-03 Use LM4040DIM3X-5.0/NOPB for U2
    - Set the U2 value on the schematic and PCB to LM4040DIM3X-5.0/NOPB
    - Update the BOM to match, and regenerate gerbers, drill files, zip and the SMD CPL
    [Attenuverter-B_Cu.gbr, Attenuverter-B_Mask.gbr, Attenuverter-B_Paste.gbr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]
2026-10-04 Update PCB version label to v1.1
    [Attenuverter.kicad_pcb]
2026-10-04 Label input clamp diodes as 1N4148WS-7-F
    [Attenuverter.kicad_sch]
2026-10-07 Faceplate: squeezed wordmark footer, Orbitron text
    Replaces the lower-left S-mark with the new 2mm-squeezed full wordmark
    (_NTSFootprints:SchentronicsLogoSqueeze2mm), centered in the gap right
    of the bottom screw hole (0.80mm margin each side). Adds ST-03, vertical,
    centered in the left gap, anchored to the wordmark's bottom. Header and
    part number switched from KiCad's italic stroke font to upright Orbitron.
    Note: this file carries other pending local changes from before this
    edit (titleblock/zone data), not just the faceplate update above.
    [AttenuverterFaceplate.kicad_pcb]
2026-10-07 Faceplate: align mounting-hole X-offset to 7.5mm, re-anchor wordmark/ST-03
    Both rack-screw holes move from ~7.4986/7.4972mm off the left edge to
    exactly 7.5mm, matching the other three boards. Wordmark and ST-03
    shift by the same ~0.0014mm to stay centered off the new hole position.
    [AttenuverterFaceplate.kicad_pcb]
2026-10-07 Faceplate: move header to the common 8.25mm top offset
    Brings this board in line with the other three (it had drifted to
    7.85mm). Also fixes a real clearance problem, not just consistency:
    at 7.85mm the header's vertical gap to the top screw head left only
    0.35mm of margin -- Orbitron is wide enough that the text's left edge
    already runs past the hole horizontally, so that vertical gap was the
    only thing protecting it. 8.25mm doubles the margin to 0.75mm.
    Note: docs/images/panel.svg here is generated by a script that still
    expects the pre-KiCad-10 Edge.Cuts/module syntax, so it couldn't be
    regenerated -- flagging as pre-existing, not something this touched.
    [AttenuverterFaceplate.kicad_pcb]
2026-10-07 Title blocks: logo worksheet, consistent company/rev across PCB and schematic
    Repoint page_layout_descr_file (both pcbnew and schematic) from the old
    Windows path to the real one on this machine, so the Schenktronics
    worksheet -- and its embedded logo -- actually loads.
    Fill out/correct title blocks: company standardized to "Schenktronics"
    (was "Nathan Schenk"), and PCB rev brought up to 1.1 to match both the
    real "v1.1" silkscreen text and the schematic's already-correct 1.1 --
    the PCB title block had been stuck at the old 1.0. Faceplate matched to
    the same 1.1 for consistency within the product.
    [Attenuverter.kicad_pcb, Attenuverter.kicad_sch, AttenuverterFaceplate.kicad_pcb]
2026-10-07 Title block: add Dolibarr PCB ref (PCB-ST03-MAIN / PCB-ST03-FACE) as comment 4
    [Attenuverter.kicad_pcb, Attenuverter.kicad_sch, AttenuverterFaceplate.kicad_pcb]
2026-10-07 Main PCB: harmonize branding text with the Multiple's pattern
    Reformatted "Attenuverter\nv1.1" to "ST-03 v1.1\nAttenuverter" (code +
    version first, name second), matching the Multiple's layout convention.
    Logo stays as the medium S-mark, already in a clear spot.
    Tried adding the CC BY-NC-SA roundels + text too, matching the Multiple,
    but this board is far more densely routed (active circuit vs. the
    Multiple's passive jacks-only layout) -- verified via kicad-cli renders
    that every candidate spot collided with real pads or traces, so left
    them off rather than force an overlap. Space, not a fixed rule, is
    what decided this per board.
    [Attenuverter.kicad_pcb]
2026-10-08 Regenerate gerbers: new rev, branding, and worksheet logo position
    Main board picks up rev 1.1 (was still 1.0 in the last gerber set) and
    the harmonized ST-03 branding text. Faceplate picks up the squeezed
    wordmark, tick marks, and the 7.5mm hole-offset fix.
    Dropped the stale *-F_SilkS.gbr/*-B_SilkS.gbr files on the faceplate --
    this KiCad version names the silkscreen layer "Silkscreen" not "SilkS",
    so the old short-named files were dead weight alongside the new ones.
    Same for the old NPTH-drl_map.plt (not a format kicad-cli produces;
    replaced by the PDF map). Both zips rebuilt to match.
    [Attenuverter-B_Cu.gbr, Attenuverter-B_Mask.gbr, Attenuverter-B_Paste.gbr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]
2026-10-08 Restructure into hardware/ and manufacturing/, matching Quad Mixer's layout
    Attenuverter/ -> hardware/attenuverter/ (source) and manufacturing/attenuverter/
    (gerbers plus the SMD placement CSV, moved out). AttenuverterFaceplate/ ->
    hardware/panel/ and manufacturing/panel/ (gerbers plus the panel .dxf).
    KiCad project filenames are unchanged, only their containing folder moved.
    Updates the drawing scripts' hardcoded paths, README's repository-layout
    diagram, and the manual/BOM links.
    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
    [Attenuverter-B_Cu.gbr, Attenuverter-B_Mask.gbr, Attenuverter-B_Paste.gbr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]
2026-10-08 Remove stale KiCad legacy/cache/backup files
    - Attenuverter.sch: the old EESchema format schematic, superseded by
    Attenuverter.kicad_sch (which .kicad_pro's top_level_sheets already
    names as the real schematic, is newer, and embeds all 45 of its own
    symbols -- fully self-contained). Updated the manual's schematic link
    to point at .kicad_sch instead, and dropped the now-inaccurate
    '(KiCad 5)' caption.
    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
    [Attenuverter.sch]
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2026-10-09 Generate mechanical outline drawings from the assembly STEP file
    Replaces the product photos in the README, manual and assembly guide
    with real HLR projections of the module straight from the STEP files
    in hardware/: a front view, a side profile, four isometric hero-angle
    candidates, and a bare panel+PCB view for the assembly guide's "before
    you start" shot.
    With 9 jacks on the front panel (more than either the Multiple or
    Levels), the front view hit the same coaxial-barrel degenerate case
    documented in the shared generator, but the existing perspective-
    projection fix handled it cleanly in one pass. The side view segfaulted
    once and succeeded on retry, isolated to that one view by the
    gene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
2026-10-09 Switch to a non-detent pot; fix an obsolete LM4040 part number
    New BOM: Bourns PTV09A-4020F-B104 (bushingless, no center detent),
    replacing PTV09A-4225F-B104. Same mounting style and KiCad footprint as
    before (both are the PTV09 family's bushingless rear-mount variant,
    differing only in shaft length and detent option per Bourns' ordering
    code), so no footprint change is needed — only the BOM, the docs that
    described the detent, and the panel/patch drawing scripts' comments.
    The knob (Davies 1221-J) is unchanged.
    Also fixes U2's part number: the old LM4040DIM3X-5.0/NOPB (TI's legacy
    M3X-suffix ordering format) showed up Obsolete with no price at Mouser.
    TI's current datasheet confirms the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
    [Attenuverter.kicad_sch, BOM.csv]
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2026-10-09 Stop tracking generated manufacturing files
    [Attenuverter-B_Cu.gbr, Attenuverter-B_Mask.gbr, Attenuverter-B_Paste.gbr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]
